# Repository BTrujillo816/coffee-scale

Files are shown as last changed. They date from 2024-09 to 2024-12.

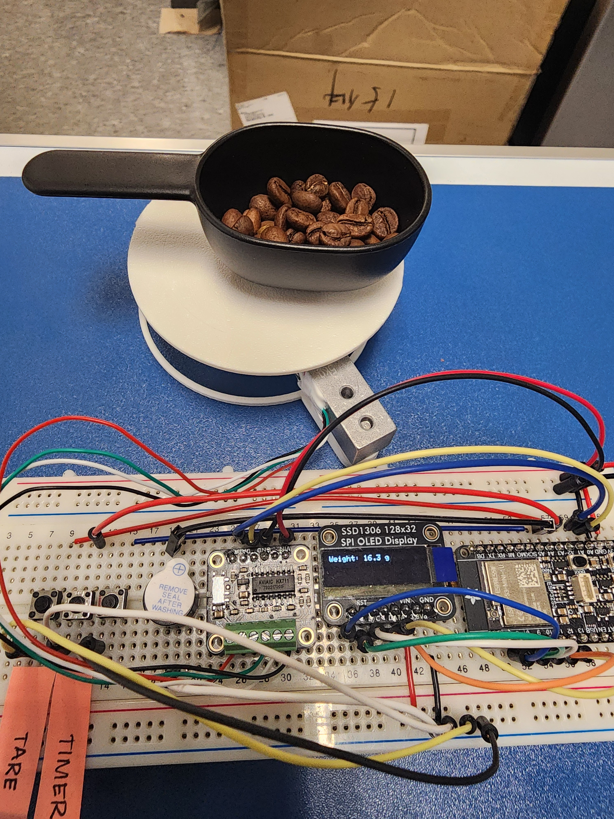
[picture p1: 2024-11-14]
documentation/TestDocument.assets/Small_weight_test_result.jpg

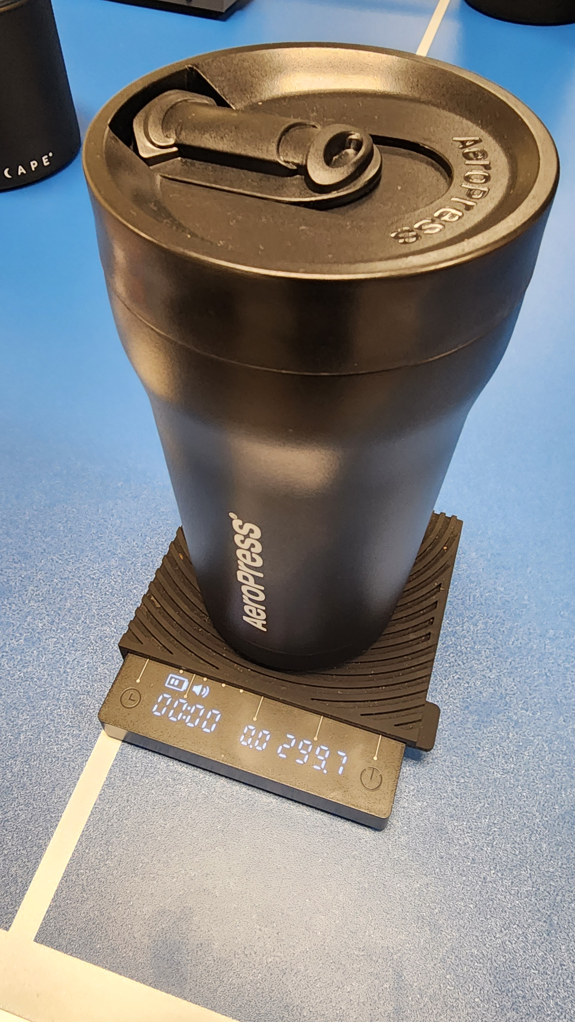
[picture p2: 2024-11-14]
documentation/TestDocument.assets/Medium_weight_test_control.jpg

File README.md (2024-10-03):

# ECET 430 Project: Digital Coffee Scale

This is a project for NJIT's ECET 430 - Electronics Manufacturing class.

## Purpose

This digital coffee scale will display weight measurements, flow rate, and include a built-in timer. It will also be able to send brew parameters through WiFi or Bluetooth to an App or other interface.

## Repo Layout

- `hardware` KiCad project with schematic, pcb layout, plots, drawings
- `software` ESP32 firmware and Arduino IDE setup
- `documentation` Technical documentation and user manual
- `logbook` Markdown files for progress updates

## Usage

See the [user documentation](documentation/UserDocumentation.md).

## Design

See the [design decision document](documentation/DesignDecisions.md).

## Credit

This project was made possible by borrowing from great designs, including:

- ABC's wearable widget, https://github.com/example/project
- XYZ's battery management, https://github.com/example/otherproject

## Author

Written by Brandon Trujillo and Miguel Takinan, 2024

## License

This work is available under the [Creative Commons Attribution-ShareAlike License 4.0](https://en.wikipedia.org/wiki/Wikipedia:Text_of_the_Creative_Commons_Attribution-ShareAlike_4.0_International_License). A local copy is available at [LICENSE.md](LICENSE.md).

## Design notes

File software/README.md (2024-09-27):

# Digital Coffee Scale Software

ESP32-S3 firmware project

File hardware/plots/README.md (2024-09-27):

# Digital Coffee Scale Hardware

PCB renderings, schematic PDFs, board images

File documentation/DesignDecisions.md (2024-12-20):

# Major Moving Parts
- Power
    - Battery
        - LIPO
            - MCP73831-based circuit for charging
- UI
    - Display
    - Buttons
- Enclosure
    - Laser Cut Acrylic
    - 3D Printed
- Microcontroller
    - ESP32
- Sensors
    - Load Cell
    - HX711
# Sections/Block Diagram
```mermaid 
flowchart TD
    A[ESP32] 
    B[Power]
    A -->C[User Interface] --> D[OLED Display] 
    A -->E[Enclosure] --> F[3D Printed Case]
    A -->G[Sensors] --> |HX711|I[Load Cell] 
    B -->K[LiPo]
    B -->L[MCP7831]
```
# Design Approaches
- Uses LiPo battery for rechargeability
- Uses ESP32 for its IoT capabilities i.e WiFi and Bluetooth
- Uses an E-ink display over LCD/LED to save on power consumption
- Uses an HX711 to interface with the load cell easily

# Major Component Selection
- MCP73831: https://www.digikey.com/en/products/detail/microchip-technology/MCP73831T-2ACI-OT/964301
- LiPo Battery: https://www.digikey.com/en/products/detail/sparkfun-electronics/PRT-13851/6605199
- eInk Display: https://www.digikey.com/en/products/detail/adafruit-industries-llc/1028/10650647
- ESP32: https://www.digikey.com/en/products/detail/adafruit-industries-llc/5885/22596418
- Load Cell: https://www.digikey.com/en/products/detail/adafruit-industries-llc/4540/12323569
- HX711 Breakout: https://www.digikey.com/en/products/detail/adafruit-industries-llc/5974/24639130

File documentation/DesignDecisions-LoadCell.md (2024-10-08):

# Load Cell + HX711 Design Decisions

## Calculations

### Load Cell

#### Voltage Output

$$V_{OUT}=V_{S}\times V_{E}$$

- $V_{OUT}$: Output from Load Cell
- $V_S$: Voltage Sensitivity
- $V_E$ = Excitation Voltage

### HX711

#### Full Scale Input Differential Voltage (FSR)

- Gain of 128: $\pm 20mV$
- Gain of 64: $\pm 40mV$
- Gain of 32: $\pm 80mV$

#### ADC Step Size

The data output from the ADC is a 24-bit 2's complement value.

ADC Step Size $= \frac{FSR\times2}{2^{24}}$

#### Saturation

[In Progress]

## Example Situation

Given a 1 kg Load Cell with $V_{S}=20 \space mV/V$ sensitivity and an excitation voltage of $V_E=5 \space V$

Max Output Voltage: 

$V_{OUT}=20\space mV/V\times5 \space V=100\space mV$

If an object weighs 500 g, then the output voltage (input into HX711) would be

$V_{OUT}=\frac{500}{1000}\times100=50\space mV$

If the input signal into the HX711 were to exceed these the Full Scale Input Differential Voltage, the output from the HX711 would be saturated.

$50 \space mV$ is beyond the range of $\pm 20mV$ and $\pm 40mV$; therefore, the only appropriate gain value to use is 32, which gives a range of $\pm 80mV$

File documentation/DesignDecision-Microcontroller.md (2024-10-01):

### Microcontroller Options

- ESP32-S3
- Arduino

### Pros and Cons

- ESP32-S3

  - Pros
    - IoT Capability (Bluetooth and Wi-Fi)
    - Arduino IDE compatible
    - Greater processing speed
    - Sleep modes
  - Cons
    - More expensive than ATMEGA328PB-MU
    - Smaller operational voltage range (2.2 to 3.6V)
- ATMEGA328PB-MU

  - Pros
    - Greater operational voltage range (1.8 to 5.5V)
    - Easier to work with (prior experience)
    - Lower power draw

  - Cons
    - No Wi-Fi without external module
    - No Bluetooth capability without external module

### Decision Factors

We decided to use an ESP32-S3 primarily because of its IoT capabilities (Wi-Fi and Bluetooth compatibility) and its compatibility with the Arduino IDE.

### Microcontroller Resources

Built-in Peripherals

- PWM
  - eInk Display
- RTC
  - External Wakeup

Connectivity	

- SPI
  - eInk Display
- BLE
  - App connectivity/data collection
- Wi-Fi
  - App connectivity/data collection

Memory Planning

- Calibration settings

GPIO

- Pushbuttons

- LEDs

- HX711

Power supply plan

- Sleep modes

### Parameters

eInk Display (UC8151d)

- Clock rate for SPI interface
- Display resolution
- Frame rate

HX711

- Sampling rate
- Gain selection

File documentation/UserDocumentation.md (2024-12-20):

# Digital Coffee Scale User Manual

## Product Purpose
- The Coffee Scale Project is designed to replicate a professional coffee scale, providing precise measurements for brewing coffee. The scale automatically weighs objects, shows brewing parameters, and interacts with the user through physical controls and oled display. The product is powered by a LiPo battery and built around the ESP32 microcontroller for versatile connectivity and functionality.

## Operation
### Initial Setup
1. Power
- Make sure battery is charged. Connect to USB-C if needs charging. 
- Press wake up button to turn product on.

2. Calibration
- Ensure the scale is on a flat surface.
- Press the Tare Button to reset the weight to zero.

### Button Functions

1. Tare Button
- Action: Press to reset the scale reading to zero.
- Feedback: The buzzer will emit a short beep, and the display will show "Scale Tared"
- Use Case: Use this when the scale is loaded with a container and you want to measure the contents only.

2. Timer Button
- Action:
    - Press once to start the timer.
    - Press again to stop the timer.
- Feedback: The buzzer will emit a short beep for each action.
- Display:
    - When running, the timer shows elapsed time in seconds (e.g., "Timer: 10 s").
    - When stopped, the timer display freezes.
- Use Case: Use this to track brewing time or other timed processes.

## Weight and Flow Rate Display

1. Weight
- Displayed as: "Weight: X.X g"
    - Updates continuously as items are added or removed.
    - Minimum detectable weight is 1 gram.

2. Flow Rate
    - Displayed as: "Flow Rate: X.X g/s"
    - Calculates the rate of weight change every second.
    - Updates if the flow rate exceeds 0.5 g/s.

## Sleep Mode

1. Activation
- The device enters deep sleep mode after 30 seconds of inactivity.
- Inactivity is defined as:
    - Weight below 1 gram.
    - Timer is not running.

2. Wake-Up
- Press the wake-up button to reactivate the device.

## Maintenance
1. Clean the scale surface regularly to ensure accurate readings
2. Avoid overloading the strain gauge to prevent damage
3. Recharge the battery periodically to maintain portability

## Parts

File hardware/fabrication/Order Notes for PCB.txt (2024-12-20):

Order Notes for PCB

Project Name: Coffee Scale PCB
Dimensions: 71.5 mm x 43.25 mm

Instructions:
If any errors or discrepancies are identified in the provided files, you have my authorization to make any necessary adjustments to ensure the board works as intended.

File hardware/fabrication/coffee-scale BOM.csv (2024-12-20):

Reference | Value | Footprint | Qty | MPN
C1,C2,C3,C4,C5,C6 | 10uF | Capacitor_SMD:C_1206_3216Metric_Pad1.33x1.80mm_HandSolder | 6
C7,C9 | 100nF | Capacitor_SMD:C_1206_3216Metric_Pad1.33x1.80mm_HandSolder | 2
C8 | 10uf | Capacitor_SMD:C_1206_3216Metric_Pad1.33x1.80mm_HandSolder | 1
C10,C11 | 20p | Capacitor_SMD:C_1206_3216Metric_Pad1.33x1.80mm_HandSolder | 2
D1 | ~ | Diode_SMD:D_SOD-128 | 1 | PMEG4050EP,115
D2 | LED | LED_SMD:LED_1206_3216Metric_Pad1.42x1.75mm_HandSolder | 1
D4 | D_Schottky_Filled | Diode_SMD:D_SOD-128 | 1 | DMG2301L-7
J1 | Conn_01x08 | Connector_PinHeader_2.54mm:PinHeader_1x08_P2.54mm_Vertical | 1
J2 | Conn_01x04 | Connector_PinHeader_2.54mm:PinHeader_1x04_P2.54mm_Vertical | 1
J3 | Conn_01x02 | Connector_JST:JST_PH_S2B-PH-K_1x02_P2.00mm_Horizontal | 1
J4 | USB C | Connector_USB:USB_C_Receptacle_GCT_USB4085 | 1 | USB4085-GF-A
LS1 | Speaker | Buzzer_Beeper:Buzzer_12x9.5RM7.6 | 1
Q1 | DMG3415U | Package_TO_SOT_SMD:SOT-23 | 1 | DMG2301L-7
Q2 | S8550 | Package_TO_SOT_SMD:SOT-23-3 | 1 | S8550
Q3 | BSS138 | Package_TO_SOT_SMD:SOT-23 | 1 | BSS138
R1,R2 | 100k | Resistor_SMD:R_1206_3216Metric_Pad1.30x1.75mm_HandSolder | 2
R3,R4,R9,R10 | 5.1k | Resistor_SMD:R_1206_3216Metric_Pad1.30x1.75mm_HandSolder | 4
R5,R6,R7,R8 | 100 | Resistor_SMD:R_1206_3216Metric_Pad1.30x1.75mm_HandSolder | 4
R11 | 10k | Resistor_SMD:R_1206_3216Metric_Pad1.30x1.75mm_HandSolder | 1
R12,R13 | 22 | Resistor_SMD:R_1206_3216Metric_Pad1.30x1.75mm_HandSolder | 2
SW1,SW2,SW3 | SW_Push | Button_Switch_SMD:SW_SPST_Omron_B3FS-105xP | 3
TP1,TP2,TP3,TP4,TP5,TP6 | TestPoint_Small | -- mixed values -- | 6
U1 | ESP32-S3 | RF_Module:ESP32-S3-WROOM-1 | 1 | ESP32-S3-WROOM-1-N16
U2 | HX711 | Package_SO:SOP-16_3.9x9.9mm_P1.27mm | 1 | HX711
U3 | MCP73832-5-OT | Package_TO_SOT_SMD:SOT-23-5 | 1 | MCP73832T-5ACI/OT
U4 | AP2112/RT9080-3.3 | Package_TO_SOT_SMD:SOT-89-5_Handsoldering | 1 | AP2112R5-3.3TRG1

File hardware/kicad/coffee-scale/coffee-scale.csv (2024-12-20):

Reference | Footprint | Qty | MPN
C1,C2,C3,C4,C5,C6 | Capacitor_SMD:C_1206_3216Metric_Pad1.33x1.80mm_HandSolder | 6
C7,C9 | Capacitor_SMD:C_1206_3216Metric_Pad1.33x1.80mm_HandSolder | 2
C8 | Capacitor_SMD:C_1206_3216Metric_Pad1.33x1.80mm_HandSolder | 1
C10,C11 | Capacitor_SMD:C_1206_3216Metric_Pad1.33x1.80mm_HandSolder | 2
D1 | Diode_SMD:D_SOD-128 | 1 | PMEG4050EP,115
D2 | LED_SMD:LED_1206_3216Metric_Pad1.42x1.75mm_HandSolder | 1
D4 | Diode_SMD:D_SOD-128 | 1 | DMG2301L-7
J1 | Connector_PinHeader_2.54mm:PinHeader_1x08_P2.54mm_Vertical | 1
J2 | Connector_PinHeader_2.54mm:PinHeader_1x04_P2.54mm_Vertical | 1
J3 | Connector_JST:JST_PH_S2B-PH-K_1x02_P2.00mm_Horizontal | 1
J4 | Connector_USB:USB_C_Receptacle_GCT_USB4085 | 1 | USB4085-GF-A
LS1 | Buzzer_Beeper:Buzzer_12x9.5RM7.6 | 1
Q1 | Package_TO_SOT_SMD:SOT-23 | 1 | DMG2301L-7
Q2 | Package_TO_SOT_SMD:SOT-23-3 | 1 | S8550
Q3 | Package_TO_SOT_SMD:SOT-23 | 1 | BSS138
R1,R2 | Resistor_SMD:R_1206_3216Metric_Pad1.30x1.75mm_HandSolder | 2
R3,R4,R9,R10 | Resistor_SMD:R_1206_3216Metric_Pad1.30x1.75mm_HandSolder | 4
R5,R6,R7,R8 | Resistor_SMD:R_1206_3216Metric_Pad1.30x1.75mm_HandSolder | 4
R11 | Resistor_SMD:R_1206_3216Metric_Pad1.30x1.75mm_HandSolder | 1
R12,R13 | Resistor_SMD:R_1206_3216Metric_Pad1.30x1.75mm_HandSolder | 2
SW1,SW2,SW3 | -- mixed values -- | 3
TP1,TP2,TP3,TP4,TP5,TP6 | -- mixed values -- | 6
U1 | RF_Module:ESP32-S3-WROOM-1 | 1 | ESP32-S3-WROOM-1-N16
U2 | Package_SO:SOP-16_3.9x9.9mm_P1.27mm | 1 | HX711
U3 | Package_TO_SOT_SMD:SOT-23-5 | 1 | MCP73832T-5ACI/OT
U4 | Package_TO_SOT_SMD:SOT-89-5_Handsoldering | 1 | AP2112R5-3.3TRG1

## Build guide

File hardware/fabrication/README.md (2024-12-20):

# Digital Coffee Scale Fabrication Files

Gerbers, BOM, ordering instructions

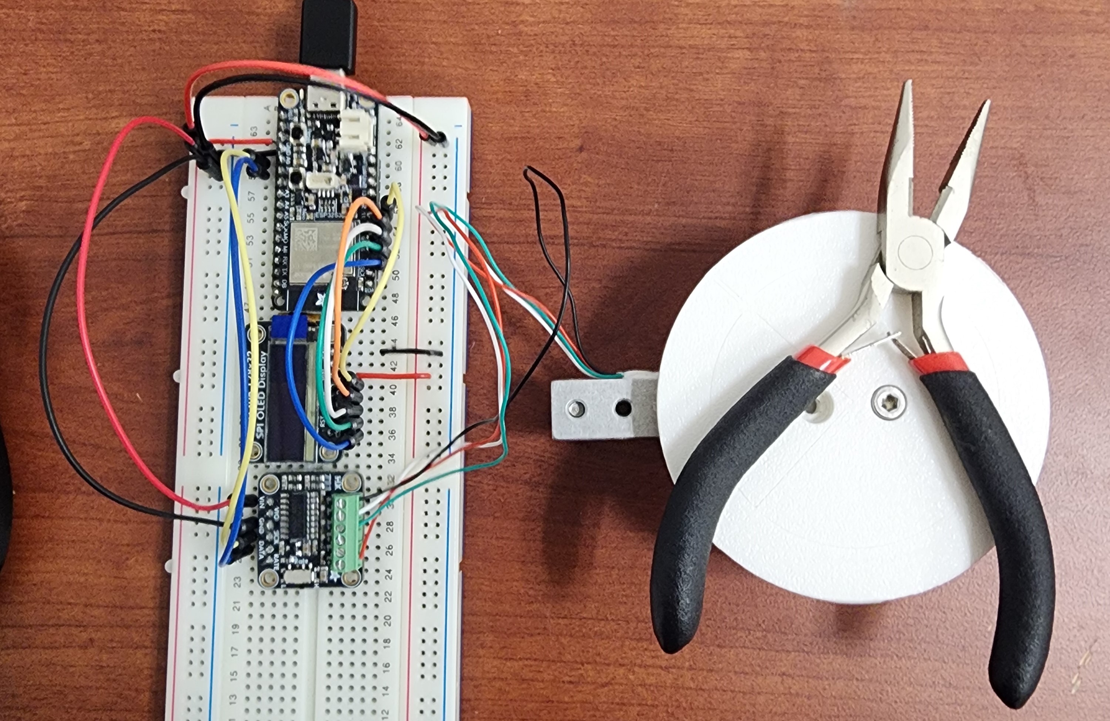
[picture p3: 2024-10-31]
logbook/10-30-24.assets/Wiring.jpg

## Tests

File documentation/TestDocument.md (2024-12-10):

# Test Document

## Precision Testing

### Test 1 - Does it show the same value for a given object?

#### Equipment Used

- Coffee Grinder
- Timemore [Black Mirror Nano Scale](https://www.timemore.com/products/timemore-black-mirror-nano-espresso-coffee-weighing-timing-black)
- [Breadboard prototype](https://github.com/BTrujillo816/coffee-scale/blob/main/documentation/TestDocument.assets/Current_prototype_11-13-24.jpg)

#### Criteria

- Given: An object of known weight
- When: The object is removed and placed again
- Then: The scale should display the same value each time
- Acceptable Range: $\pm10$%

#### Results

| Placement | Control (g) | Test (g) | Percent Error (%) |
| --- | --- | --- | --- |
| 1 | 380.4 | 380.3 | 0.02 |
| 2 | 380.4 | 380.4 | 0 |
| 3 | 380.4 | 380.5 | 0.05 |

The object was picked up and placed three times after the initial placement, as seen in the [video](https://github.com/BTrujillo816/coffee-scale/blob/main/documentation/TestDocument.assets/Test_Precision.mp4). The results of this test fall within the acceptable range, therefore the system is precise. However, the weight output tends to fluctuate, likely due to noise.

### Test 2 - Does it show the same value over a long period of time?

#### Equipment Used

- Coffee Grinder
- Timemore [Black Mirror Nano Scale](https://www.timemore.com/products/timemore-black-mirror-nano-espresso-coffee-weighing-timing-black)
- [Breadboard prototype](https://github.com/BTrujillo816/coffee-scale/blob/main/documentation/TestDocument.assets/Current_prototype_11-13-24.jpg)

#### Criteria

- Given: An object of known weight
- When: The object remains on the scale for an extended period of time
- Then: The scale should continuously show the same weight for the same period of time
- Acceptable Range: $\pm 5$%

#### Results

| Time (s) | Control (g) | Test (g) | Percent Error (%) |
| --- | --- | --- | --- |
| 5 | 298.7 | 298.4 | 0.10 |
| 15 | 298.7 | 298.5 | 0.07 |
| 30 | 298.7 | 298.9 | 0.07 |

When an object remains on the scale, the weight display tends to fluctuate; however, because the fluctuations are within an acceptable range below 5%, the system is still precise. The weight fluctuation could be potentially be solved through noise reduction measures and a redesign the load cell chassis.

## Accuracy Testing

### Test 1 - Benchmark weight against existing products

#### Equipment Used

- Coffee scoop (light weight)
- Metal bottle (medium weight)
- Coffee Grinder (heavy weight)
- Timemore [Black Mirror Nano Scale](https://www.timemore.com/products/timemore-black-mirror-nano-espresso-coffee-weighing-timing-black)
- [Breadboard prototype](https://github.com/BTrujillo816/coffee-scale/blob/main/documentation/TestDocument.assets/Current_prototype_11-13-24.jpg)

#### Criteria

- Acceptable Range: $\pm 10%$%

#### Results

| Object | Control (g) | Test (g) | Percent Error (%) |
| --- | --- | --- | --- |
| Coffee Scoop | [16.3](https://github.com/BTrujillo816/coffee-scale/blob/main/documentation/TestDocument.assets/Small_weight_test_control.jpg) | [16.3](https://github.com/BTrujillo816/coffee-scale/blob/main/documentation/TestDocument.assets/Small_weight_test_result.jpg) | 0 |
| Metal Bottle | [299.7](https://github.com/BTrujillo816/coffee-scale/blob/main/documentation/TestDocument.assets/Medium_weight_test_control.jpg) | [299.3](https://github.com/BTrujillo816/coffee-scale/blob/main/documentation/TestDocument.assets/Medium_weight_test_result.jpg) | 0.13 |
| Coffee Grinder | [380.8](https://github.com/BTrujillo816/coffee-scale/blob/main/documentation/TestDocument.assets/Large_weight_test_control.jpg) | [380.2](https://github.com/BTrujillo816/coffee-scale/blob/main/documentation/TestDocument.assets/Large_weight_test_result.jpg) | 0.15 |

All tests were within an acceptable range, therefore, our system is accurate.

### Test 2 - Benchmark time against computer/phone clock

#### Equipment Used

- Timemore [Black Mirror Nano Scale](https://www.timemore.com/products/timemore-black-mirror-nano-espresso-coffee-weighing-timing-black)
- Breadboard prototype

#### Criteria

- Acceptable Range: $\pm 5$%

#### Results

As shown in the [video](https://github.com/BTrujillo816/coffee-scale/blob/main/documentation/TestDocument.assets/Test_Timer.mp4), both timers seem to increment at the same rate. Therefore, we can say that our system is accurate in its timing.

### Test 3 - Benchmark flow-rate calculation against existing products

#### Equipment Used

- Timemore [Black Mirror Nano Scale](https://www.timemore.com/products/timemore-black-mirror-nano-espresso-coffee-weighing-timing-black)
- [Breadboard](https://github.com/BTrujillo816/coffee-scale/blob/main/documentation/TestDocument.assets/Current_prototype_11-13-24.jpg) prototype
- Metal cup
- Paper cup

#### Criteria

- Given: Water flows from a container at a known flow rate
- When: Water flows onto the scale
- Then: The scale should display an accurate flow rate measurement

#### Result

We have determined from our [test](https://github.com/BTrujillo816/coffee-scale/blob/main/documentation/TestDocument.assets/Functionality_Flow_Rate.mp4) that a more consistent, controllable method should be used to measure flow rate. In the future, we'll use an object that provides a consistent flow rate (such as a funnel) and benchmark the scale against the Timemore scale.

## Manual Testing

#### Equipment Used

- Timemore [Black Mirror Nano Scale](https://www.timemore.com/products/timemore-black-mirror-nano-espresso-coffee-weighing-timing-black) (or any timer)
- [Breadboard](https://github.com/BTrujillo816/coffee-scale/blob/main/documentation/TestDocument.assets/Current_prototype_11-13-24.jpg) prototype
- Any weight

#### Test 1 - Check sleep timer functionality after inactivity

#### Procedure

- Wake up the scale by pressing the wakeup button
- Place weight on scale and wait 30 seconds
- Observe if the scale remains on after 30 seconds
- Remove weight and leave the scale idle for 30 seconds
- Observe if the scale automatically powers off after 30 seconds

- Pass Criteria: The scale turns on when power button is pressed and turns off after 30 seconds of no activity

#### Result

In the [video](https://github.com/BTrujillo816/coffee-scale/blob/main/documentation/TestDocument.assets/Test_Timer.mp4), an object is placed on the scale to prevent the system from going to sleep. At 32 seconds, the object is removed and the system shuts off 30 seconds later at 1:02. This accurate shows the sleep timer is functioning properly.

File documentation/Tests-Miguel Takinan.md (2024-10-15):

# Test Criterias by Miguel Takinan

## Guides
1. [Automatic vs Manual Testing](https://www.geeksforgeeks.org/software-engineering-differences-between-manual-and-automation-testing/)
2. [Given-When-Then](https://martinfowler.com/bliki/GivenWhenThen.html)

## Test
1. Power and Auto-off Functionality
    - Test Type: Manual
    - Objective: Check the power functions and auto-off function after inactivity
    - Test Steps:
        - Turn the scale on by pressing the power button
        - Leave the scale idle for 30 seconds
        - Observe if the scale automatically powers off after 30 seconds
    - Pass Criteria: The scale turns on when power button is pressed and turns off after 30 seconds of no activity

2. Accuracy of Weight Measurement
    - Test Type: Manual, Given-When-Then
    - Objective: Ensure the scale measures weight accurately
    - Test Steps:
        - Given an accurate weight of 100g
        - When the weight is placed on the scale
        - Then the scale should display the correct weight of 100g
    - Pass Criteria: The displayed weight is correct within a small margin of error

3. Display Accuracy and Speed
    - Test Type: Manual, Given-When-Then
    - Objective: Ensure the display shows weight measurements accurately and updates in real-time without noticeable delay
    - Test Steps:
        - Given the scale is powered on
        - When a series of weights starting from 0g, 50g and 100g are placed on the scale one at a time
        - Then the display should show the correct weight for each measurement immediately
    - Pass Criteria: The display shows the correct weight for each tested weight within one second

4. Flow Rate Detection
    - Test Type: Manual
    - Objective: Ensure the scale accurately detects and displays flow rate
    - Test Steps:
        - Start pouring water slowly onto a container placed on the scale
        - Observe if the scale continuously displays the flow rate in grams per second
        - Compare flow rate readings against a stopwatch and a graduated cylinder for accuracy
    - Pass Criteria: The scale’s flow rate closely matches the manual measurements

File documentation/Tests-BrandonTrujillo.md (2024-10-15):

# Tests - Brandon Trujillo

## Performance Testing

Types-of-Performance-testing-1024

### Load Testing

What happens when a weight that exceeds the Load Cell's rating is placed on the scale?

- Test different types of loads
  - Anticipated loads
  - Excessive loads

### Endurance Testing

**Precision**

- Does it show the same value for a given object?
  - Given: An object of known weight
  - When: The object is removed and placed again
  - Then: The scale should display the same value each time
- Does it show the same value over a long period of time?
  - Given: An object of known weight
  - When: The object remains on the scale for an extended period of time
  - Then: The scale should continuously show the same weight for the same period of time

### Benchmark Testing

**Accuracy**

- Benchmark weight against existing products
- Benchmark time against computer/phone clock
- Benchmark flow-rate calculation against existing products

### Speed Testing

- Measure execution time of each section of code
  - Print time of execution to serial monitor

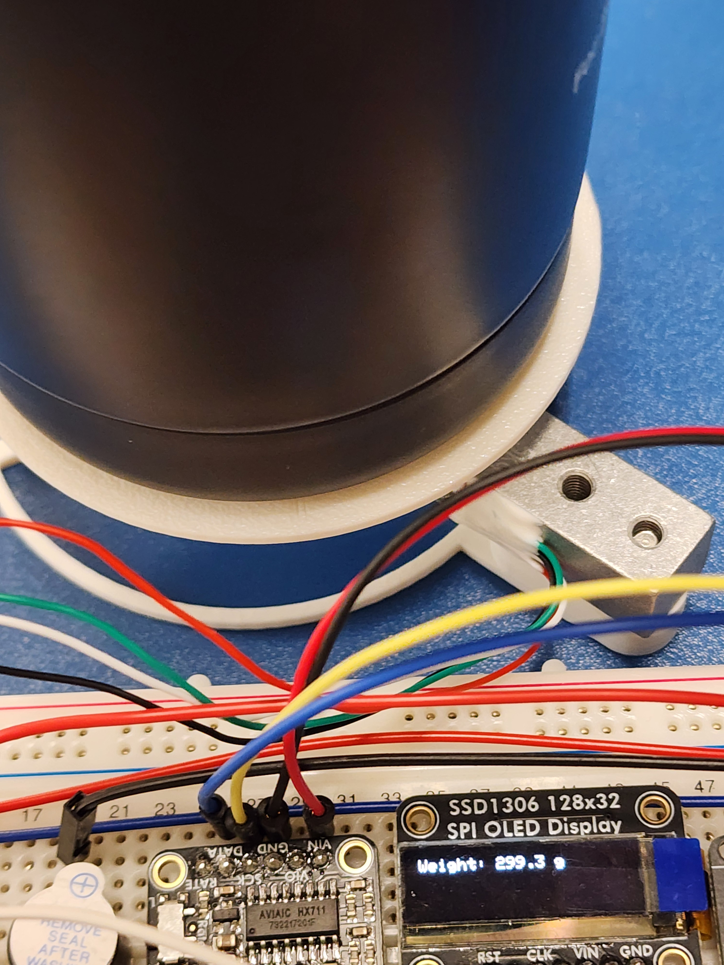
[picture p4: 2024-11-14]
logbook/11-13-24.assets/Medium_weight_test_result.jpg

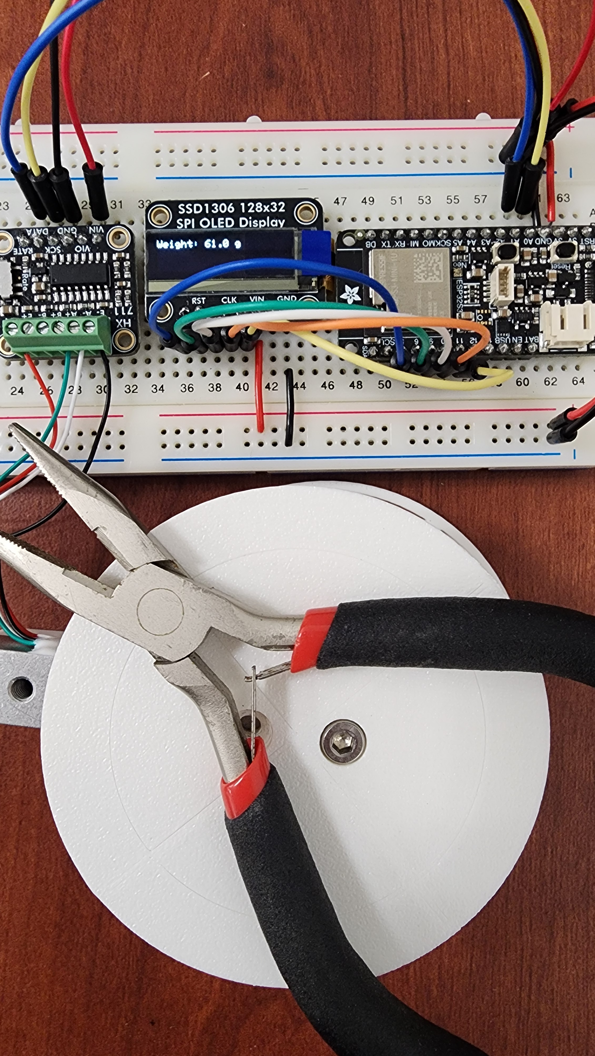
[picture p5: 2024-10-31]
logbook/10-30-24.assets/Result_Oled_LoadCell_Test.jpg

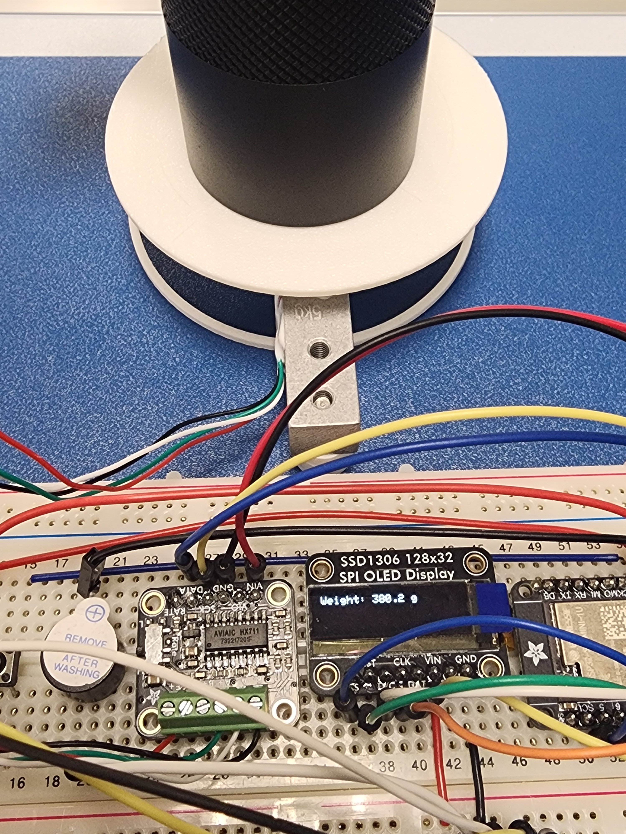
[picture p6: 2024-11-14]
logbook/11-13-24.assets/Large_weight_test_result.jpg

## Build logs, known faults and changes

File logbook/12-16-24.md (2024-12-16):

# 12/16/2024
## PCB Edits
    - Changed ESP32 footprint
    - Changed USB footprint
    - Finished routing all traces
    - DRC found no errors except some warnings

## DRC Errors
    - Copper zone being cut off because of running traces on the bottom layer
        - Causing ground connection issues(annoying issue to tackle)
            - Made bottom layer traces as close to each other and only as needed
            - Made sure theres no island copper fill
    - Ignored USB and PCB clearance errors
    - Minor errors all around like having a silkscreen minumum height of .8 mm were fixed

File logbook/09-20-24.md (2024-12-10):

# 09-20-24

## [Blink an LED with an ESP32](https://github.com/BTrujillo816/coffee-scale/issues/6)

### Components

- ESP32-S3
- $220 \ohm$ resistor
- LED

### Notes

- [Wokwi Project](https://wokwi.com/projects/409566066184866817)

- I used this [tutorial](https://makeabilitylab.github.io/physcomp/esp32/led-blink.html) to blink a singular LED on Wokwi

## [Use ESP32 to interface with HX711 and Load Cell in Wokwi](https://github.com/BTrujillo816/coffee-scale/issues/7)

### Components

- ESP32-S3
- HX711
- Load Cell

### Notes

[Wokwi Project](https://wokwi.com/projects/409582446772088833)

- I used the Example Arduino Sketch from the [Hobby Components forum post](https://forum.hobbycomponents.com/viewtopic.php?f=73&t=1763) by Andrew Davies
  - I prefer this to using the HX711 Arduino library as I eventually want to learn how to implement this in ESP-IDF using C.
    - The HX711 datasheet contains a reference driver in both ASM and C

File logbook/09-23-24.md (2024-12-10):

# 09-23-24

## [Interface with eInk Display using ESP32 on Wokwi](https://github.com/BTrujillo816/coffee-scale/issues/9)

### Details

- Status: Incomplete
- Hardware
  - ESP32-S3
  - ePaper 2.9"
- Software
  - Wokwi
  - C++

### Notes

- I cannot find an example Wokwi project using the [Adafruit EDP Library](https://github.com/adafruit/Adafruit_EPD) that works properly

  - The error seems to be with the GXEPD2 library

    - ```
      Error installing GxEPD2: Library install failed: testing local archive integrity: testing archive size: fetched archive size differs from size specified in index: 176128 != 4501132
      ```

- I'll need to learn how to upload custom libraries
  - It might be easier if I set up Wokwi for VS Code

## [Start Project Schematic](https://github.com/BTrujillo816/coffee-scale/issues/10)

### Details 

- Status: Incomplete
- Software
  - KiCAD

### Notes

- We needed to make a custom symbol within KiCAD
  - This can be found within
- I cannot figure out what electrical type MISO and MOSI should be
  - [Related Forum Post](https://forum.kicad.info/t/electrical-type-for-spi-device-miso-pins/9444)
- I think Adafruit really wants us to use a breakout board to interface with the eInk display
  - Without it, we'd have to solder headers onto the display if we wanted to use it on a breadboard

### Misc

```
// 2.9" Tricolor Featherwing or Breakout with UC8151D chipset
// ThinkInk_290_Tricolor_Z13 display(EPD_DC, EPD_RESET, EPD_CS, SRAM_CS,
// EPD_BUSY, EPD_SPI);
```

- I found this on the [Adafruit EDP Library](https://github.com/adafruit/Adafruit_EPD). This might give insight on to what data pins actually matter.

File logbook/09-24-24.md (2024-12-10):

# 09-24-24

## [Start Project Schematic](https://github.com/BTrujillo816/coffee-scale/issues/10)

### Details

- Status: Version 001
- Hardware
  - ESP32-S3
  - HX711
  - Custom UC8151D
  - Custom Strain Gauge
  - MCP72831

### Wiring Guide

#### Load Cell Wiring Guide to HX711
    - E+ (red wire) stands for Excitation Positive of the load cell
        - Connects to the Analog Voltage Supply Pin (AVDD/VIN) of the HX711
    - E- (black ire) stands for Excitation Negative of the load cell
        - Connects to the Analog Ground (AGND/GND) of the HX711
    - A+ (white wire) stands for Signal Positive of the load cell
        - Connects to the Positive Input for channel A (INA+ or A+) of the XH711
    - A- (green wire) stands for Signal Negative of the load cell
        - Connect to the Negative Input for channel A (INA- or A-) of the HX711
    
    *** Important: Since no datasheet came with the acquired load cell. Assume manufacturer followed this convention.
        1. Red Wire (E+): Positive excitation
        2. Black Wire (E-): Negative excitation
        3. White Wire (A+): Positive signal output
        4. Green Wire (A-): Negative signal output

#### HX711 to ESP32-S3
    - HX711 SCK (Serial Clock) or PD_SCK 
        - Connect to any GPIO
    - HX711 DATA (Data Output) or DOUT
        - Connect to any GPIO
    - HX711 E+ (Excitation Positive)
        - Connect to AVDD/VIN
    - HX711 E- (Excitation Negative)
        - Connect to GND

#### ESP32 to E-ink Display
    - Power Connections:
        - VIN → Connect to 5V (or 3.3V, depending on your display’s requirement)
        - 3.3V → Connect to VDD3P3 on the ESP32-S3
        - GND → Connect to GND on the ESP32-S3
    
    - SPI Connections:
        - SCK → Connect to SCK of ESP32-S3 (GPIO36 on the ESP32-S3 Feather)
        - MISO → Connect to MISO of ESP32-S3 (GPIO37 on the ESP32-S3 Feather)
        - MOSI → Connect to MOSI of ESP32-S3 (GPIO35 on the ESP32-S3 Feather)
        - ECS (Chip Select) → Connect to any GPIO 
        - D/C (Data/Command) → Connect to any GPIO
        - SRCS (Source Select) → Connect to any GPIO 
        - SDCS (Data Chip Select) → Connect to any GPIO 
        - RST (Reset) → Connect to any GPIO
        - BUSY → Connect to any GPIO
        - ENA (Enable) → Connect to any GPIO
    
    *** Necessary Pins for E-ink Display
        - SCK: Required for clocking the data into the E-ink display.
        - MISO: Typically used for data feedback from the E-ink display to the ESP32-S3. Not always necessary unless display requires it for certain operations (like reading status).
        - MOSI: Essential for sending data from the ESP32-S3 to the E-ink display.
        - ECS: This is important to tell the E-ink display when to listen to the data being sent. Without this, the display may not respond correctly.
        - D/C : Important for distinguishing between data and command instructions sent to the display. It helps the display interpret what type of data it is receiving.
        - RST: Often required to initialize the display. Without this, may not be able to reset the display or clear it properly.
    
    *** Optional Pinks for E-ink Display 
        - BUSY: Indicates when the display is busy processing data. It's useful for synchronizing operations but may not be strictly necessary for all applications.
        - SRCS: Might be used to select between different sources for data or power. Depending on your display.
        - SDCS: Similar to ECS, this pin is likely used to select the data source. If display has both ECS and SDCS, check the documentation to see if both are necessary, as sometimes they can serve similar purposes.
        - ENA: Typically enables or disables the display. It may be required to power on the display or enable certain functions. It's a common pin in various display modules.

### Notes

- ESP32-S3 has a lot more features than your standard ESP32. I am wondering if we should build this with an ESP32 instead of mounting on a ESP32-S3.

## [Interface with eInk display using ESP32-S3 IRL](https://github.com/BTrujillo816/coffee-scale/issues/11)

### Details

- Status: Incomplete
- Hardware:
  - Adafruit ESP32-S3 Feather
  - R: 220 $\ohm$ 
  - LED (Red)

### Soldering Headers

- In order to breadboard with these components, we had to solder headers onto the ESP32-S3, EYESPI Breakout Board, and HX711 breakout board
  - HX711
    - Might need to reflow some solder joints

### Notes

``````
A fatal error occurred: Could not open COM6, the port doesn't exist
Failed uploading: uploading error: exit status 2
``````

In order to solve this error, I have attempted the following:

- Uninstalled and reinstalled Arduino IDE
- Downloaded and installed CP210x USB to UART Bridge VCP Drivers from [here](https://www.silabs.com/developers/usb-to-uart-bridge-vcp-drivers?tab=downloads)
- Restarted my computer multiple times
- Swapped USB-C cable

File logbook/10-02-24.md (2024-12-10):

# 10-02-24

## [Blink LED IRL](https://github.com/BTrujillo816/coffee-scale/issues/13)

### Details

- Hardware
  - Adafruit Feather ESP32-S3 8MB No PSRAM
  - LED (Red)
  - 220 $\ohm$ Resistor
- Software
  - Arduino IDE
  - C++

### Notes

After many long hours of troubleshooting, I was finally able to blink an LED following a factory reset using this [tutorial](https://learn.adafruit.com/adafruit-esp32-s3-feather/factory-reset). Huzzah!



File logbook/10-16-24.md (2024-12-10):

# 10-16-24

## [Setup Wokwi for VS Code](https://github.com/BTrujillo816/coffee-scale/issues/12)

I was able to setup Wokwi for VS Code using [Wokwi's Guide](https://docs.wokwi.com/vscode/getting-started/). I'm interested in exploring PlatformIO as an IDE for programming the physical ESP32-S3 itself.

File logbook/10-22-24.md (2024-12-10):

# 10-22-24
## [Interface with HX711 and Load Cell IRL](https://github.com/BTrujillo816/coffee-scale/issues/14)

### Adafruit Example Code

```c++
#include <Arduino.h>
#include "HX711.h"

// HX711 circuit wiring
const int LOADCELL_DOUT_PIN = 9;
const int LOADCELL_SCK_PIN = 8;

HX711 scale;

void setup() {
  Serial.begin(57600);
  Serial.println("HX711 Demo");
  Serial.println("Initializing the scale");

  scale.begin(LOADCELL_DOUT_PIN, LOADCELL_SCK_PIN);

  Serial.println("Before setting up the scale:");
  Serial.print("read: \t\t");
  Serial.println(scale.read());      // print a raw reading from the ADC

  Serial.print("read average: \t\t");
  Serial.println(scale.read_average(20));   // print the average of 20 readings from the ADC

  Serial.print("get value: \t\t");
  Serial.println(scale.get_value(5));   // print the average of 5 readings from the ADC minus the tare weight (not set yet)

  Serial.print("get units: \t\t");
  Serial.println(scale.get_units(5), 1);  // print the average of 5 readings from the ADC minus tare weight (not set) divided
            // by the SCALE parameter (not set yet)
            
  scale.set_scale(765);
  //scale.set_scale(-471.497);                      // this value is obtained by calibrating the scale with known weights; see the README for details
  scale.tare();               // reset the scale to 0

  Serial.println("After setting up the scale:");

  Serial.print("read: \t\t");
  Serial.println(scale.read());                 // print a raw reading from the ADC

  Serial.print("read average: \t\t");
  Serial.println(scale.read_average(20));       // print the average of 20 readings from the ADC

  Serial.print("get value: \t\t");
  Serial.println(scale.get_value(5));   // print the average of 5 readings from the ADC minus the tare weight, set with tare()

  Serial.print("get units: \t\t");
  Serial.println(scale.get_units(5), 1);        // print the average of 5 readings from the ADC minus tare weight, divided
            // by the SCALE parameter set with set_scale

  Serial.println("Readings:");
}

void loop() {
  Serial.print("one reading:\t");
  Serial.print(scale.get_units(), 1);
  Serial.print("\t| average:\t");
  Serial.println(scale.get_units(10), 5);

  delay(5000);
}
```

### Random Nerd Tutorials Code

```c++
/*
  Rui Santos
  Complete project details at https://RandomNerdTutorials.com/arduino-load-cell-hx711/

  Permission is hereby granted, free of charge, to any person obtaining a copy
  of this software and associated documentation files.

  The above copyright notice and this permission notice shall be included in all
  copies or substantial portions of the Software.
*/

// Calibrating the load cell
#include "HX711.h"

// HX711 circuit wiring
const int LOADCELL_DOUT_PIN = 2;
const int LOADCELL_SCK_PIN = 3;

HX711 scale;

void setup() {
  Serial.begin(57600);
  scale.begin(LOADCELL_DOUT_PIN, LOADCELL_SCK_PIN);
}

void loop() {

  if (scale.is_ready()) {
    scale.set_scale();    
    Serial.println("Tare... remove any weights from the scale.");
    delay(5000);
    scale.tare();
    Serial.println("Tare done...");
    Serial.print("Place a known weight on the scale...");
    delay(5000);
    long reading = scale.get_units(10);
    Serial.print("Result: ");
    Serial.println(reading);
  } 
  else {
    Serial.println("HX711 not found.");
  }
  delay(1000);
}

//calibration factor will be the (reading)/(known weight)
```

### Notes

- The test code from adafruit library was not working as intended
    - The output is either 0 or some constant value that does not change no matter how much pressure is applied to the gauge

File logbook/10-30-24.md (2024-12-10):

# 10-30-24

## [Update schematic to include OLED display](https://github.com/BTrujillo816/coffee-scale/issues/18)

### General

- Added OLED (SSD1306) [datasheet](../coffee-scale\documentation\assets\SSD1306.pdf) to documentation branch

### Eagle File to KiCAD

- Why does Adafruit only offer Eagle files :c

### Symbol Creation

- Figured out that we don't need it anyways
  - Added 08x02 connectors to socket display

## [Make a Nice Readable Schematic](https://github.com/BTrujillo816/coffee-scale/issues/16)

### LiPo Battery Charger

- Replaced SparkFun ESP32 Thing circuit with prettier circuit from Adafruit ESP32-S3 Feather 

### Power and Filtering

- Changed custom JST connector to boring KiCAD 01x02 connector
  - I should place this on the left side to have it function clearly as an input

### Load Cell

- Edited symbol so no wires crisscross

### ADC

- Added No Connect flags

### Microcontroller

- Added No Connect flags

### Display

- Made wiring nice and pretty
- Added text
  - I should add more text about the actual display

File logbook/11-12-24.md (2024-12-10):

# 11-12-24

## [Add USB-C receptacle to schematic](https://github.com/BTrujillo816/coffee-scale/issues/24)

### General

- Added USB-C receptable

- Read this [article](https://dubiouscreations.com/2021/04/06/designing-with-usb-c-lessons-learned/) to learn more about reasoning behind design

  image-6-450x312

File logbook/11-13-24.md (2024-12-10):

# 11-13-24

## [Add pushbuttons to prototype](https://github.com/BTrujillo816/coffee-scale/issues/25)

- Added three button to do three different functionalities
    - Tare feature to zero the scale after putting weight when button is pressed
    - Timer function that starts to count and show on the OLED display when the button is pressed
    - Wake up
- Added an active buzzer for sound effects    

## [Configure Deep Sleep mode](https://github.com/BTrujillo816/coffee-scale/issues/23)

- Added a deep sleep mode by following this [website](https://randomnerdtutorials.com/esp32-deep-sleep-arduino-ide-wake-up-sources/)
- Currently, the threshold weight for deep sleep is <1g 

## [Create flow rate display algorithm](https://github.com/BTrujillo816/coffee-scale/issues/20)

- Although this works, we still need to figure out a better method of testing

## [Run tests on breadboard prototype](https://github.com/BTrujillo816/coffee-scale/issues/26)

- Tested the core functionalities of our prototype for our midterm presentation
    - More details can be found in our [testing document](https://github.com/BTrujillo816/coffee-scale/blob/main/documentation/TestDocument.md)
- Scale
    - Accuracy Test
        - Benchmarked three different objects to determine the scale's accuracy
    - Precision Test
        - Weighed the same object multiple times to determine consistency
- Timer
    - Ran a known timer at the same time to determine accuracy
- Deep sleep timer
    - Tested deep sleep timer by letting an object rest for more than 30 seconds, removing it, and then waiting

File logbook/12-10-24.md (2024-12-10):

# 12/10/24
## PCB Design
### Footprint
- Mostly chose the 1206 because apparently is SMD soldering friendly
- Some footprints like the USB and JSTPH im unsure of

### Routing
- Initially tried to do bottom copper as ground plane but having a hard time connecting signal traces in a two layer pcb
- resorted to going back to orthogonal method.
- Ended up mixing both.
    - Not the best routing/tracing job. 
    - Removed all the error in DRC.
        - Hopefully it works

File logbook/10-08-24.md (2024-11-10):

# 10-08-24

## [Create a Nice Readable Schematic](https://github.com/BTrujillo816/coffee-scale/issues/16)

### Rules/Conventions

- Signals should flow from left to right

- PWR on top, GND always down
  - 
- Lines should never be on an angle
  - Up, down, left, right
- Never, **ever** have lines going through your chip symbols
- Annotations should be horizontal
  - The person shouldn't have to tilt their head to read them

- Designators and their values can either be together on one side, or on opposite sides of a symbol

  - Just make sure you are consistent

- Set pins to snap grid when creating symbols

- No need to show footprints on schematic

- Net name should be on top of netlist/lines

- Don't assign nets to things that have ports (+3V3 net when you have a 3V3 port)

- Avoid crossing wires if possible

  - Edit symbol to move pins even if it doesn't match the physical layout

- Don't label nets if you are not going to use them

- Signify if a symbol is going out to prevent confusion (someone might think it's a completed circuit)

  



- Don't run wires through the schematic if you don't have to

- Connectors don't have to be next to the components; however, you must properly label the nets

- Net names should be meaningful and nonredundant

- Either change the symbol to all match the physical in mapping or group them up by functionality so that they support signal flow
  - If you edit for symbol flow, make sure that the inputs are on the left and outputs are on the right
- Be consistent with schematic symbols i.e. for capacitors, resistors
- Do not use decimal points for values in your schematic
  - 0.01uF > 100nF or 100n
- Use ports for outputs
- Label sections with notes
- Make LEDS and other symbols vertical
- Don't create four way junctions off a single node
- Designators can be renamed if you truly need to but keep it short and sweet
- Use A4 schematic size since we're yankees

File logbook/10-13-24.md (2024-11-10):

# 10-13-24

## [Interface with eInk display using ESP32-S3 IRL](https://github.com/BTrujillo816/coffee-scale/issues/11)

### Example Code for E-Ink from Adafruit
```
#include "Adafruit_ThinkInk.h"

#define EPD_DC 10
#define EPD_CS 5
#define EPD_BUSY -1 // can set to -1 to not use a pin (will wait a fixed delay)
#define SRAM_CS 11
#define EPD_RESET 9  // can set to -1 and sh\are with microcontroller Reset!
#define EPD_SPI &SPI // primary SPI

ThinkInk_290_Tricolor_Z13 display(EPD_DC, EPD_RESET, EPD_CS, SRAM_CS, EPD_BUSY, EPD_SPI);

void setup() {
  Serial.begin(115200);
  while (!Serial) {
    delay(10);
  }
  Serial.println("Adafruit EPD full update test in red/black/white");
  display.begin(THINKINK_TRICOLOR);
}

void loop() {
  Serial.println("Banner demo");
  display.clearBuffer();
  display.setTextSize(3);
  display.setCursor((display.width() - 144) / 2, (display.height() - 24) / 2);
  display.setTextColor(EPD_BLACK);
  display.print("Tri");
  display.setTextColor(EPD_RED);
  display.print("Color");
  display.display();

  delay(15000);

  Serial.println("Color rectangle demo");
  display.clearBuffer();
  display.fillRect(display.width() / 3, 0, display.width() / 3,
                   display.height(), EPD_BLACK);
  display.fillRect((display.width() * 2) / 3, 0, display.width() / 3,
                   display.height(), EPD_RED);
  display.display();

  delay(15000);

  Serial.println("Text demo");
  // large block of text
  display.clearBuffer();
  display.setTextSize(1);
  testdrawtext(
      "Lorem ipsum dolor sit amet, consectetur adipiscing elit. Curabitur "
      "adipiscing ante sed nibh tincidunt feugiat. Maecenas enim massa, "
      "fringilla sed malesuada et, malesuada sit amet turpis. Sed porttitor "
      "neque ut ante pretium vitae malesuada nunc bibendum. Nullam aliquet "
      "ultrices massa eu hendrerit. Ut sed nisi lorem. In vestibulum purus a "
      "tortor imperdiet posuere. ",
      EPD_BLACK);
  display.display();

  delay(15000);

  display.clearBuffer();
  for (int16_t i = 0; i < display.width(); i += 4) {
    display.drawLine(0, 0, i, display.height() - 1, EPD_BLACK);
  }

  for (int16_t i = 0; i < display.height(); i += 4) {
    display.drawLine(display.width() - 1, 0, 0, i, EPD_RED);
  }
  display.display();

  delay(15000); # 15 second delay before going into the next display
}

void testdrawtext(const char *text, uint16_t color) {
  display.setCursor(0, 0);
  display.setTextColor(color);
  display.setTextWrap(true);
  display.print(text);
}

- Note when this code ran
    - Multiple flickering inbetween display changes

- Other issues
    - The process can be confusing to have the ESP32 execute the code to the E-Ink
        - Things that worked
            - Have to select the USB port again after it compiles
            - Have to press the reset button on the ESP32

- EYESPI Breakout
    - https://learn.adafruit.com/adafruit-eyespi-breakout-board/pinouts
```

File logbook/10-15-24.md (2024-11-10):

# 10-15-24

## [Interface with HX711 and Load Cell IRL](https://github.com/BTrujillo816/coffee-scale/issues/14)

### Wiring from Load Cell to HX711

- Red wire to E+
- Black wire to E-
- Green wire to B+
- White wire t0 B-

### Wiring from HX711 to ESP32-S3

- VIN (Red wire) to 3V
- GND (Black wire) to GND
- DATA (Yellow wire) to GPIO8/A5
- SCK (Blue wire) to GPIO14/A4

### Library

- Adafruit_HX711 library

### HX711 Schematics

https://learn.adafruit.com/adafruit-hx711-24-bit-adc/downloads

### Example Code

```c++
#include "Adafruit_HX711.h"

// Define the pins for the HX711 communication
const uint8_t DATA_PIN = 2;  // Can use any pins!
const uint8_t CLOCK_PIN = 3; // Can use any pins!

Adafruit_HX711 hx711(DATA_PIN, CLOCK_PIN);

void setup() {
  Serial.begin(115200);

  // wait for serial port to connect. Needed for native USB port only
  while (!Serial) {
    delay(10);
  }

  Serial.println("Adafruit HX711 Test!");

  // Initialize the HX711
  hx711.begin();

  // read and toss 3 values each
  Serial.println("Tareing....");
  for (uint8_t t=0; t<3; t++) {
    hx711.tareA(hx711.readChannelRaw(CHAN_A_GAIN_128));
    hx711.tareA(hx711.readChannelRaw(CHAN_A_GAIN_128));
    hx711.tareB(hx711.readChannelRaw(CHAN_B_GAIN_32));
    hx711.tareB(hx711.readChannelRaw(CHAN_B_GAIN_32));
  }
} 

void loop() {
  // Read from Channel A with Gain 128, can also try CHAN_A_GAIN_64 or CHAN_B_GAIN_32
  // since the read is blocking this will not be more than 10 or 80 SPS (L or H switch)
  int32_t weightA128 = hx711.readChannelBlocking(CHAN_A_GAIN_128);
  Serial.print("Channel A (Gain 128): ");
  Serial.println(weightA128);

  // Read from Channel A with Gain 128, can also try CHAN_A_GAIN_64 or CHAN_B_GAIN_32
  int32_t weightB32 = hx711.readChannelBlocking(CHAN_B_GAIN_32);
  Serial.print("Channel B (Gain 32): ");
  Serial.println(weightB32);
}
```

### Issues

- Serial monitor always outputs zero even after applying pressure to the strain gauge

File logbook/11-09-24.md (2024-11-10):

# 11-09-24

## [Update "Stage 2: ADC" based on "Figure 4. Reference PCB Board Schematic"](https://github.com/BTrujillo816/coffee-scale/issues/19)

### General

- Updated Stage 1 and Stage 2 based on Figure 4 on HX711 datasheet

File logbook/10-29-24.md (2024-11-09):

# 10-29-24

## [Interface with OLED display IRL](https://github.com/BTrujillo816/coffee-scale/issues/17)

### Components

- [SPI OLED Display 128x32](https://www.adafruit.com/product/661)
- Arduino Uno

I followed this [Adafruit Guide](https://learn.adafruit.com/monochrome-oled-breakouts/wiring-128x32-spi-oled-display) to test the SPI OLED on an Arduino Uno.

This code can be found in [here](../software/ino/ssd1306_128x32_spi/ssd1306_128x32_spi.ino)

### Adafruit ESP32 Feather

- Load Cell: Successfully calibrated and now measures weight with acceptable tolerance
- OLED Display: Functions as intended when tested with example code
- Integration: Preliminary code to connect the load cell and OLED display
  - Code found [here](../software/ino/OLED_LoadCell_Code/Oled_LoadCell_Code.ino)
  - Result found [here](../logbook/10-30-24.assets/Result_Oled_LoadCell_Test.jpg) 

- Power/Wiring issues
  - OLED display or HX711 does not receive power at certain points along the power rail
    - This was evident when rewiring peripherals
    - As of right now, [this](../logbook/10-30-24.assets/Wiring.jpg) setup works
- Our known weight is a 60.3 grams [plier](../logbook/10-30-24.assets/Test_Weight.jpg)
  - The result is acceptable, as can be seen from this [image](../logbook/10-30-24.assets/Result_LoadCell_Test.png)

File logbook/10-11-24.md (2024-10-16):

# 10-11-24

## [Interface with eInk display using ESP32-S3 IRL](https://github.com/BTrujillo816/coffee-scale/issues/11)

- Installed "adafruit_EPD", "adafruit GFX", and "adafruit ImageReader" library from arduino
- From https://github.com/adafruit/Adafruit_EPD, I downloaded and moved the src folder to the arduino library folder

So far the example code I copied has finally compiled. Next goal is to try and change image in the display. However, will need to verify the pin connections again.

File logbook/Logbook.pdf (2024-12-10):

09-20-24

# Blink an LED with an ESP32 (https://github.com/BTrujillo816/coffee-scale/issues/6)

# Components

## ESP32-S3 resistor LED

# Notes

## Wokwi Project (https://wokwi.com/projects/409566066184866817)

I used this tutorial (https://makeabilitylab.github.io/physcomp/esp32/led-blink.html) to blink a singular LED on Wokwi

# Use ESP32 to interface with HX711 and Load Cell in Wokwi (https://github.com/BTrujillo816/coffee-scale/issues/7)

# Components

## ESP32-S3

HX711

## Load Cell

# Notes

## Wokwi Project (https://wokwi.com/projects/409582446772088833)

I used the Example Arduino Sketch from the Hobby Components forum post (https://forum.hobbycomponents.com/viewtopic.php?f=73&t=1763) by Andrew Davies

## I prefer this to using the HX711 Arduino library as I eventually want to learn how to

implement this in ESP-IDF using C.

## The HX711 datasheet contains a reference driver in both ASM and C

09-23-24
Interface with eInk Display using ESP32 on Wokwi (https://github.com/BTrujillo816/coffee-scale/issues/9)

# Details

## Status: Incomplete Hardware ESP32-S3

## ePaper 2.9" Software Wokwi

C++

# Notes

I cannot find an example Wokwi project using the Adafruit EDP Library (https://github.com/adafruit/Adafruit_EPD) that works properly

## The error seems to be with the GXEPD2 library

## I'll need to learn how to upload custom libraries It might be easier if I set up Wokwi for VS Code

# Start Project Schematic (https://github.com/BTrujillo816/coffee-scale/issues/10)

# Details

## Status: Incomplete Software

## KiCAD

# Notes

## We needed to make a custom symbol within KiCAD

## This can be found within I cannot figure out what electrical type MISO and MOSI should be

Related Forum Post (https://forum.kicad.info/t/electrical-type-for-spi-device-miso-pins/9444)
I think Adafruit really wants us to use a breakout board to interface with the eInk display

Error installing GxEPD2: Library install failed: testing local archive integrity: testing archive size: fetched archive size differs from size

## Without it, we'd have to solder headers onto the display if we wanted to use it on a breadboard

# Misc

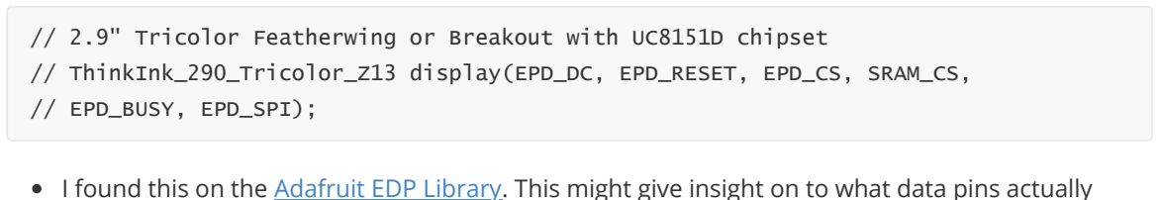
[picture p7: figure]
// EPD_BUSY, EPD_SPI);

I found this on the Adafruit EDP Library. (https://github.com/adafruit/Adafruit_EPD) This might give insight on to what data pins actually matter.

// 2.9" Tricolor Featherwing or Breakout with UC8151D chipset
// ThinkInk_290_Tricolor_Z13 display(EPD_DC, EPD_RESET, EPD_CS, SRAM_CS,

09-24-24

# Start Project Schematic (https://github.com/BTrujillo816/coffee-scale/issues/10)

# Details

## Status: Version 001 Hardware ESP32-S3

HX711

## Custom UC8151D Custom Strain Gauge

## MCP72831

# Wiring Guide

# Load Cell Wiring Guide to HX711

# HX711 to ESP32-S3

- E+ (red wire) stands for Excitation Positive of the load cell
- Connects to the Analog Voltage Supply Pin (AVDD/VIN) of the HX711
- E- (black ire) stands for Excitation Negative of the load cell
- Connects to the Analog Ground (AGND/GND) of the HX711
- A+ (white wire) stands for Signal Positive of the load cell
- Connects to the Positive Input for channel A (INA+ or A+) of the XH711
- A- (green wire) stands for Signal Negative of the load cell
- Connect to the Negative Input for channel A (INA- or A-) of the HX711

*** Important: Since no datasheet came with the acquired load cell. Assume manufacturer followed this convention.
1. Red Wire (E+): Positive excitation
2. Black Wire (E-): Negative excitation
3. White Wire (A+): Positive signal output
4. Green Wire (A-): Negative signal output

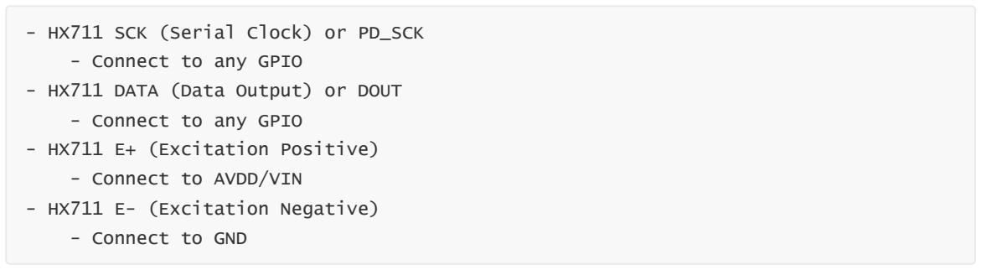
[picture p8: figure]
- HX711 SCK (Serial Clock) or PD_SCK; - Connect to any GPIO; - HX711 DATA (Data Output) or DOUT; - HX711 E+ (Excitation Positive); - Connect to AVDD/VIN; - HX711 E- (Excitation Negative); - Connect to GND

# ESP32 to E-ink Display

# Notes

ESP32-S3 has a lot more features than your standard ESP32. I am wondering if we should build this with an ESP32 instead of mounting on a ESP32-S3.

- Power Connections:
- VIN → Connect to 5V (or 3.3V, depending on your display’s requirement)
- 3.3V → Connect to VDD3P3 on the ESP32-S3
- GND → Connect to GND on the ESP32-S3
- SPI Connections:
- SCK → Connect to SCK of ESP32-S3 (GPIO36 on the ESP32-S3 Feather)
- MISO → Connect to MISO of ESP32-S3 (GPIO37 on the ESP32-S3 Feather)
- MOSI → Connect to MOSI of ESP32-S3 (GPIO35 on the ESP32-S3 Feather)
- ECS (Chip Select) → Connect to any GPIO
- D/C (Data/Command) → Connect to any GPIO
- SRCS (Source Select) → Connect to any GPIO
- SDCS (Data Chip Select) → Connect to any GPIO
- RST (Reset) → Connect to any GPIO
- BUSY → Connect to any GPIO
- ENA (Enable) → Connect to any GPIO

*** Necessary Pins for E-ink Display
- SCK: Required for clocking the data into the E-ink display.
- MISO: Typically used for data feedback from the E-ink display to the ESP32-S3. Not always necessary unless display requires it for certain operations (like reading status).
- MOSI: Essential for sending data from the ESP32-S3 to the E-ink display.
- ECS: This is important to tell the E-ink display when to listen to the data being sent. Without this, the display may not respond correctly.
- D/C : Important for distinguishing between data and command instructions sent to the display. It helps the display interpret what type of data it is receiving.
- RST: Often required to initialize the display. Without this, may not be able to reset the display or clear it properly.

*** Optional Pinks for E-ink Display
- BUSY: Indicates when the display is busy processing data. It's useful for synchronizing operations but may not be strictly necessary for all applications.
- SRCS: Might be used to select between different sources for data or power. Depending on your display.
- SDCS: Similar to ECS, this pin is likely used to select the data source. If display has both ECS and SDCS, check the documentation to see if both are necessary, as sometimes they can serve similar purposes.
- ENA: Typically enables or disables the display. It may be required to power on the display or enable certain functions. It's a common pin in various display modules.

Interface with eInk display using ESP32-S3 IRL (https://github.com/BTrujillo816/coffee-scale/issues/11)

# Details

## Status: Incomplete Hardware: Adafruit ESP32-S3 Feather

R: 220

## LED (Red)

# Soldering Headers

In order to breadboard with these components, we had to solder headers onto the ESP32-S3,

## EYESPI Breakout Board, and HX711 breakout board

HX711

## Might need to reflow some solder joints

# Notes

## In order to solve this error, I have attempted the following:

## Uninstalled and reinstalled Arduino IDE

Downloaded and installed CP210x USB to UART Bridge VCP Drivers from here (https://www.silabs.com/developers/usb-to-uart-bridge-vcp-drivers?tab=downloads)

## Restarted my computer multiple times Swapped USB-C cable

A fatal error occurred: Could not open COM6, the port doesn't exist Failed uploading: uploading error: exit status 2

10-02-24

# Blink LED IRL (https://github.com/BTrujillo816/coffee-scale/issues/13)

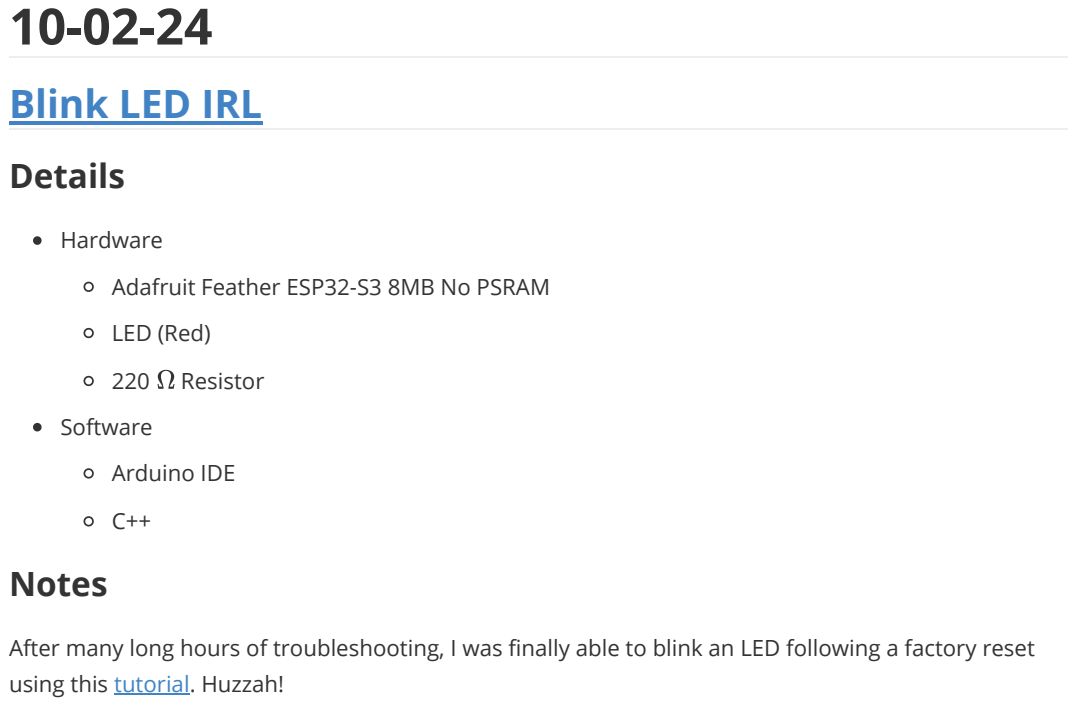
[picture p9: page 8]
Details

Hardware
Adafruit Feather ESP32-S3 8MB No PSRAM
LED (Red)
220 Resistor
Software
Arduino IDE
Notes

After many long hours of troubleshooting, I was finally able to blink an LED following a factory reset
using this tutorial. (https://learn.adafruit.com/adafruit-esp32-s3-feather/factory-reset) Huzzah!

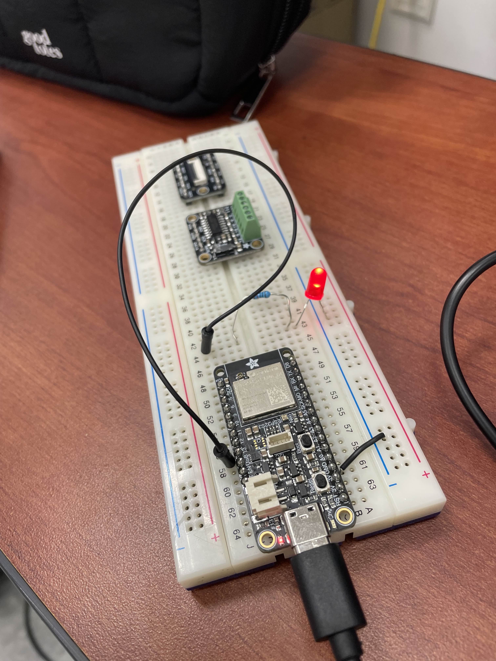
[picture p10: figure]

10-08-24

# Create a Nice Readable Schematic (https://github.com/BTrujillo816/coffee-scale/issues/16)

# Rules/Conventions

## Signals should flow from left to right PWR on top, GND always down

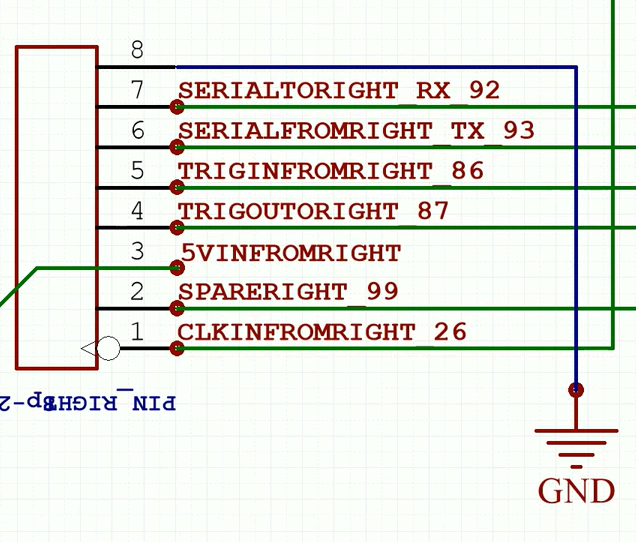
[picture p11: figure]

## Lines should never be on an angle

## Up, down, left, right Never, ever have lines going through your chip symbols Annotations should be horizontal

## The person shouldn't have to tilt their head to read them

Designators and their values can either be together on one side, or on opposite sides of a symbol

## Just make sure you are consistent

## Set pins to snap grid when creating symbols No need to show footprints on schematic Net name should be on top of netlist/lines Don't assign nets to things that have ports (+3V3 net when you have a 3V3 port)

## Avoid crossing wires if possible Edit symbol to move pins even if it doesn't match the physical layout

## Don't label nets if you are not going to use them

Signify if a symbol is going out to prevent confusion (someone might think it's a completed

## circuit)

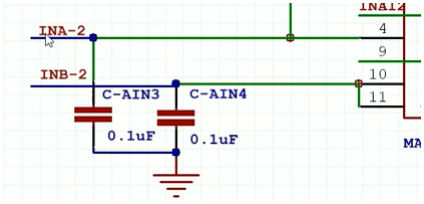
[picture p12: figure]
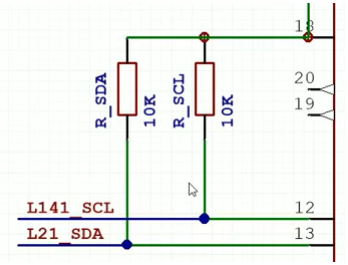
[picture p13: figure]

## Don't run wires through the schematic if you don't have to

Connectors don't have to be next to the components; however, you must properly label the nets

## Net names should be meaningful and nonredundant

Either change the symbol to all match the physical in mapping or group them up by functionality

## so that they support signal flow

If you edit for symbol flow, make sure that the inputs are on the left and outputs are on the

## right Be consistent with schematic symbols i.e. for capacitors, resistors Do not use decimal points for values in your schematic 0.01uF > 100nF or 100n

## Use ports for outputs Label sections with notes Make LEDS and other symbols vertical

## Don't create four way junctions off a single node

## Designators can be renamed if you truly need to but keep it short and sweet Use A4 schematic size since we're yankees

10-11-24
Interface with eInk display using ESP32-S3 IRL (https://github.com/BTrujillo816/coffee-scale/issues/11)

## Installed "adafruit_EPD", "adafruit GFX", and "adafruit ImageReader" library from arduino

From https://github.com/adafruit/Adafruit_EPD, I downloaded and moved the src folder to the

## arduino library folder

So far the example code I copied has finally compiled. Next goal is to try and change image in the display. However, will need to verify the pin connections again.

10-13-24
Interface with eInk display using ESP32-S3 IRL (https://github.com/BTrujillo816/coffee-scale/issues/11)

# Example Code for E-Ink from Adafruit

#include "Adafruit_ThinkInk.h"

#define EPD_DC 10

#define EPD_CS 5

#define EPD_BUSY -1 // can set to -1 to not use a pin (will wait a fixed delay) #define SRAM_CS 11

#define EPD_RESET 9 // can set to -1 and sh\are with microcontroller Reset! #define EPD_SPI &SPI // primary SPI

ThinkInk_290_Tricolor_Z13 display(EPD_DC, EPD_RESET, EPD_CS, SRAM_CS, EPD_BUSY, EPD_SPI);

void setup() {
Serial.begin(115200);
while (!Serial) {
delay(10);
}
Serial.println("Adafruit EPD full update test in red/black/white"); display.begin(THINKINK_TRICOLOR);
}

void loop() {
Serial.println("Banner demo");
display.clearBuffer();
display.setTextSize(3);
display.setCursor((display.width() - 144) / 2, (display.height() - 24) / 2); display.setTextColor(EPD_BLACK);
display.print("Tri");
display.setTextColor(EPD_RED);
display.print("Color");
display.display();

delay(15000);

Serial.println("Color rectangle demo"); display.clearBuffer();
display.fillRect(display.width() / 3, 0, display.width() / 3,
| display.height(), EPD_BLACK);
display.fillRect((display.width() * 2) / 3, 0, display.width() / 3,
| display.height(), EPD_RED);
display.display();

delay(15000);

Serial.println("Text demo"); // large block of text
display.clearBuffer();
display.setTextSize(1);
testdrawtext(
"Lorem ipsum dolor sit amet, consectetur adipiscing elit. Curabitur " "adipiscing ante sed nibh tincidunt feugiat. Maecenas enim massa, " "fringilla sed malesuada et, malesuada sit amet turpis. Sed porttitor " "neque ut ante pretium vitae malesuada nunc bibendum. Nullam aliquet " "ultrices massa eu hendrerit. Ut sed nisi lorem. In vestibulum purus a " "tortor imperdiet posuere. ",
EPD_BLACK);
display.display();

delay(15000);

display.clearBuffer();
for (int16_t i = 0; i < display.width(); i += 4) { display.drawLine(0, 0, i, display.height() - 1, EPD_BLACK); }

for (int16_t i = 0; i < display.height(); i += 4) { display.drawLine(display.width() - 1, 0, 0, i, EPD_RED); }
display.display();

delay(15000); # 15 second delay before going into the next display }

void testdrawtext(const char *text, uint16_t color) { display.setCursor(0, 0);
display.setTextColor(color); display.setTextWrap(true);
display.print(text);
}
- Note when this code ran
- Multiple flickering inbetween display changes
- Other issues
- The process can be confusing to have the ESP32 execute the code to the E-Ink
- Things that worked
- Have to select the USB port again after it compiles
- Have to press the reset button on the ESP32
- EYESPI Breakout
- https://learn.adafruit.com/adafruit-eyespi-breakout-board/pinouts

10-15-24
Interface with HX711 and Load Cell IRL (https://github.com/BTrujillo816/coffee-scale/issues/14)

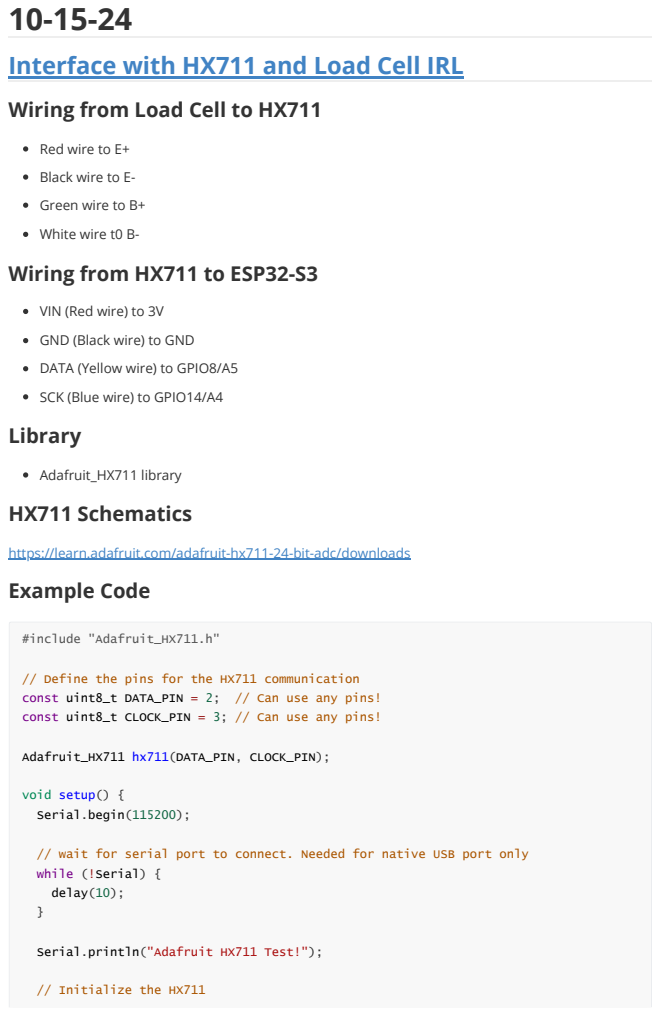
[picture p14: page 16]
Adafruit_HX711 library HX711 Schematics; #include "Adafruit_HX711.h"; const uint8_t DATA_PIN = 2;; // Can use any pins!; Adafruit_HX711 hx711(DATA_PIN, CLOCK_PIN);; void setup() {; Serial.begin(115200);; // Initialize the HX711

Wiring from Load Cell to HX711

Red wire to E+
Black wire to E-
Green wire to B+
White wire t0 B-
Wiring from HX711 to ESP32-S3

VIN (Red wire) to 3V
GND (Black wire) to GND
DATA (Yellow wire) to GPIO8/A5
SCK (Blue wire) to GPIO14/A4
Library

https://learn.adafruit.com/adafruit-hx711-24-bit-adc/downloads
Example Code

// Define the pins for the HX711 communication
const uint8_t CLOCK_PIN = 3; // Can use any pins!

// wait for serial port to connect. Needed for native USB port only
while (!Serial) {
delay(10);

Serial.println("Adafruit HX711 Test!");

# Issues

## Serial monitor always outputs zero even after applying pressure to the strain gauge

hx711.begin();

// read and toss 3 values each Serial.println("Tareing....");
for (uint8_t t=0; t<3; t++) { hx711.tareA(hx711.readChannelRaw(CHAN_A_GAIN_128)); hx711.tareA(hx711.readChannelRaw(CHAN_A_GAIN_128)); hx711.tareB(hx711.readChannelRaw(CHAN_B_GAIN_32)); hx711.tareB(hx711.readChannelRaw(CHAN_B_GAIN_32)); }
}

void loop() {
// Read from Channel A with Gain 128, can also try CHAN_A_GAIN_64 or CHAN_B_GAIN_32
// since the read is blocking this will not be more than 10 or 80 SPS (L or H switch)
int32_t weightA128 = hx711.readChannelBlocking(CHAN_A_GAIN_128); Serial.print("Channel A (Gain 128): ");
Serial.println(weightA128);

// Read from Channel A with Gain 128, can also try CHAN_A_GAIN_64 or CHAN_B_GAIN_32
int32_t weightB32 = hx711.readChannelBlocking(CHAN_B_GAIN_32); Serial.print("Channel B (Gain 32): ");
Serial.println(weightB32);
}

10-16-24

# Setup Wokwi for VS Code (https://github.com/BTrujillo816/coffee-scale/issues/12)

I was able to setup Wokwi for VS Code using Wokwi's Guide. (https://docs.wokwi.com/vscode/getting-started/) I'm interested in exploring PlatformIO as an IDE for programming the physical ESP32-S3 itself.

10-22-24
Interface with HX711 and Load Cell IRL (https://github.com/BTrujillo816/coffee-scale/issues/14)

# Adafruit Example Code

#include <Arduino.h>

#include "HX711.h"

// HX711 circuit wiring
const int LOADCELL_DOUT_PIN = 9; const int LOADCELL_SCK_PIN = 8;

HX711 scale;

void setup() {
Serial.begin(57600);
Serial.println("HX711 Demo"); Serial.println("Initializing the scale");

scale.begin(LOADCELL_DOUT_PIN, LOADCELL_SCK_PIN);

Serial.println("Before setting up the scale:");
Serial.print("read: \t\t");
Serial.println(scale.read()); | // print a raw reading from the ADC

Serial.print("read average: \t\t");
Serial.println(scale.read_average(20)); // print the average of 20 readings from the ADC

Serial.print("get value: \t\t");
Serial.println(scale.get_value(5)); // print the average of 5 readings from the ADC minus the tare weight (not set yet)

Serial.print("get units: \t\t");
Serial.println(scale.get_units(5), 1); // print the average of 5 readings from the ADC minus tare weight (not set) divided
// by the SCALE parameter (not set yet)

scale.set_scale(765);
//scale.set_scale(-471.497); | // this value is obtained by
calibrating the scale with known weights; see the README for details
scale.tare(); | // reset the scale to 0

Serial.println("After setting up the scale:");

Serial.print("read: \t\t");
Serial.println(scale.read()); | // print a raw reading from the ADC

Serial.print("read average: \t\t");

# Random Nerd Tutorials Code

Serial.println(scale.read_average(20)); | // print the average of 20 readings
from the ADC

Serial.print("get value: \t\t");
Serial.println(scale.get_value(5)); // print the average of 5 readings from the ADC minus the tare weight, set with tare()

Serial.print("get units: \t\t");
Serial.println(scale.get_units(5), 1); | // print the average of 5 readings
from the ADC minus tare weight, divided
// by the SCALE parameter set with set_scale

Serial.println("Readings:");
}

void loop() {
Serial.print("one reading:\t"); Serial.print(scale.get_units(), 1); Serial.print("\t| average:\t"); Serial.println(scale.get_units(10), 5);

delay(5000);
}

/*
Rui Santos
Complete project details at https://RandomNerdTutorials.com/arduino-load-cell-hx711/

Permission is hereby granted, free of charge, to any person obtaining a copy of this software and associated documentation files.

The above copyright notice and this permission notice shall be included in all copies or substantial portions of the Software.
*/

// Calibrating the load cell
#include "HX711.h"

// HX711 circuit wiring
const int LOADCELL_DOUT_PIN = 2; const int LOADCELL_SCK_PIN = 3;

HX711 scale;

void setup() {
Serial.begin(57600);
scale.begin(LOADCELL_DOUT_PIN, LOADCELL_SCK_PIN); }

# Notes

## The test code from adafruit library was not working as intended The output is either 0 or some constant value that does not change no matter how much pressure is applied to the gauge

void loop() {

if (scale.is_ready()) {
scale.set_scale();
Serial.println("Tare... remove any weights from the scale."); delay(5000);
scale.tare();
Serial.println("Tare done...");
Serial.print("Place a known weight on the scale..."); delay(5000);
long reading = scale.get_units(10); Serial.print("Result: ");
Serial.println(reading);
}
else {
Serial.println("HX711 not found."); }
delay(1000);
}

//calibration factor will be the (reading)/(known weight)

10-29-24

# Interface with OLED display IRL (https://github.com/BTrujillo816/coffee-scale/issues/17)

# Components

## SPI OLED Display 128x32 (https://www.adafruit.com/product/661) Arduino Uno

I followed this Adafruit Guide (https://learn.adafruit.com/monochrome-oled-breakouts/wiring-128x32-spi-oled-display) to test the SPI OLED on an Arduino Uno.

## This code can be found in here

# Adafruit ESP32 Feather

## Load Cell: Successfully calibrated and now measures weight with acceptable tolerance OLED Display: Functions as intended when tested with example code

## Integration: Preliminary code to connect the load cell and OLED display Code found here Result found here

## Power/Wiring issues OLED display or HX711 does not receive power at certain points along the power rail This was evident when rewiring peripherals

## As of right now, this setup works Our known weight is a 60.3 grams plier The result is acceptable, as can be seen from this image

10-30-24
Update schematic to include OLED display (https://github.com/BTrujillo816/coffee-scale/issues/18)

# General

Added OLED (SSD1306) datasheet (http://../coffee-scale/documentation/assets/SSD1306.pdf) to documentation branch

# Eagle File to KiCAD

## Why does Adafruit only offer Eagle files :c

# Symbol Creation

## Figured out that we don't need it anyways Added 08x02 connectors to socket display

# Make a Nice Readable Schematic (https://github.com/BTrujillo816/coffee-scale/issues/16)

# LiPo Battery Charger

Replaced SparkFun ESP32 Thing circuit with prettier circuit from Adafruit ESP32-S3 Feather

# Power and Filtering

## Changed custom JST connector to boring KiCAD 01x02 connector I should place this on the left side to have it function clearly as an input

# Load Cell

## Edited symbol so no wires crisscross

# ADC

## Added No Connect flags

# Microcontroller

## Added No Connect flags

# Display

## Made wiring nice and pretty Added text I should add more text about the actual display

11-09-24

# Update "Stage 2: ADC" based on "Figure 4. Reference PCB Board Schematic" (https://github.com/BTrujillo816/coffee-scale/issues/19)

# General

## Updated Stage 1 and Stage 2 based on Figure 4 on HX711 datasheet

11-12-24
Add USB-C receptacle to schematic (https://github.com/BTrujillo816/coffee-scale/issues/24)

# General

## Added USB-C receptable

Read this article (https://dubiouscreations.com/2021/04/06/designing-with-usb-c-lessons-learned/) to learn more about reasoning behind design

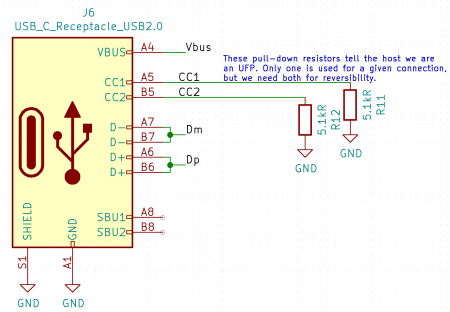
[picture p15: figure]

11-13-24

# Add pushbuttons to prototype (https://github.com/BTrujillo816/coffee-scale/issues/25)

## Added three button to do three different functionalities Tare feature to zero the scale after putting weight when button is pressed

## Timer function that starts to count and show on the OLED display when the button is pressed

## Wake up Added an active buzzer for sound effects

# Configure Deep Sleep mode (https://github.com/BTrujillo816/coffee-scale/issues/23)

Added a deep sleep mode by following this website (https://randomnerdtutorials.com/esp32-deep-sleep-arduino-ide-wake-up-sources/)

## Currently, the threshold weight for deep sleep is <1g

Create flow rate display algorithm (https://github.com/BTrujillo816/coffee-scale/issues/20)

## Although this works, we still need to figure out a better method of testing

Run tests on breadboard prototype (https://github.com/BTrujillo816/coffee-scale/issues/26)

## Tested the core functionalities of our prototype for our midterm presentation

More details can be found in our testing document (https://github.com/BTrujillo816/coffee-scale/blob/main/documentation/TestDocument.md)

## Scale Accuracy Test Benchmarked three different objects to determine the scale's accuracy

## Precision Test Weighed the same object multiple times to determine consistency Timer

## Ran a known timer at the same time to determine accuracy Deep sleep timer

Tested deep sleep timer by letting an object rest for more than 30 seconds, removing it, and

## then waiting

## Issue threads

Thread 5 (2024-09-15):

Add esp32-thing's Lithium Polymer Battery circuit to PCB schematic

BTrujillo816, 2024-09-15:
[esp32-thing-schematic.pdf](https://github.com/user-attachments/files/17007060/esp32-thing-schematic.pdf)

Closed 2024-09-24.

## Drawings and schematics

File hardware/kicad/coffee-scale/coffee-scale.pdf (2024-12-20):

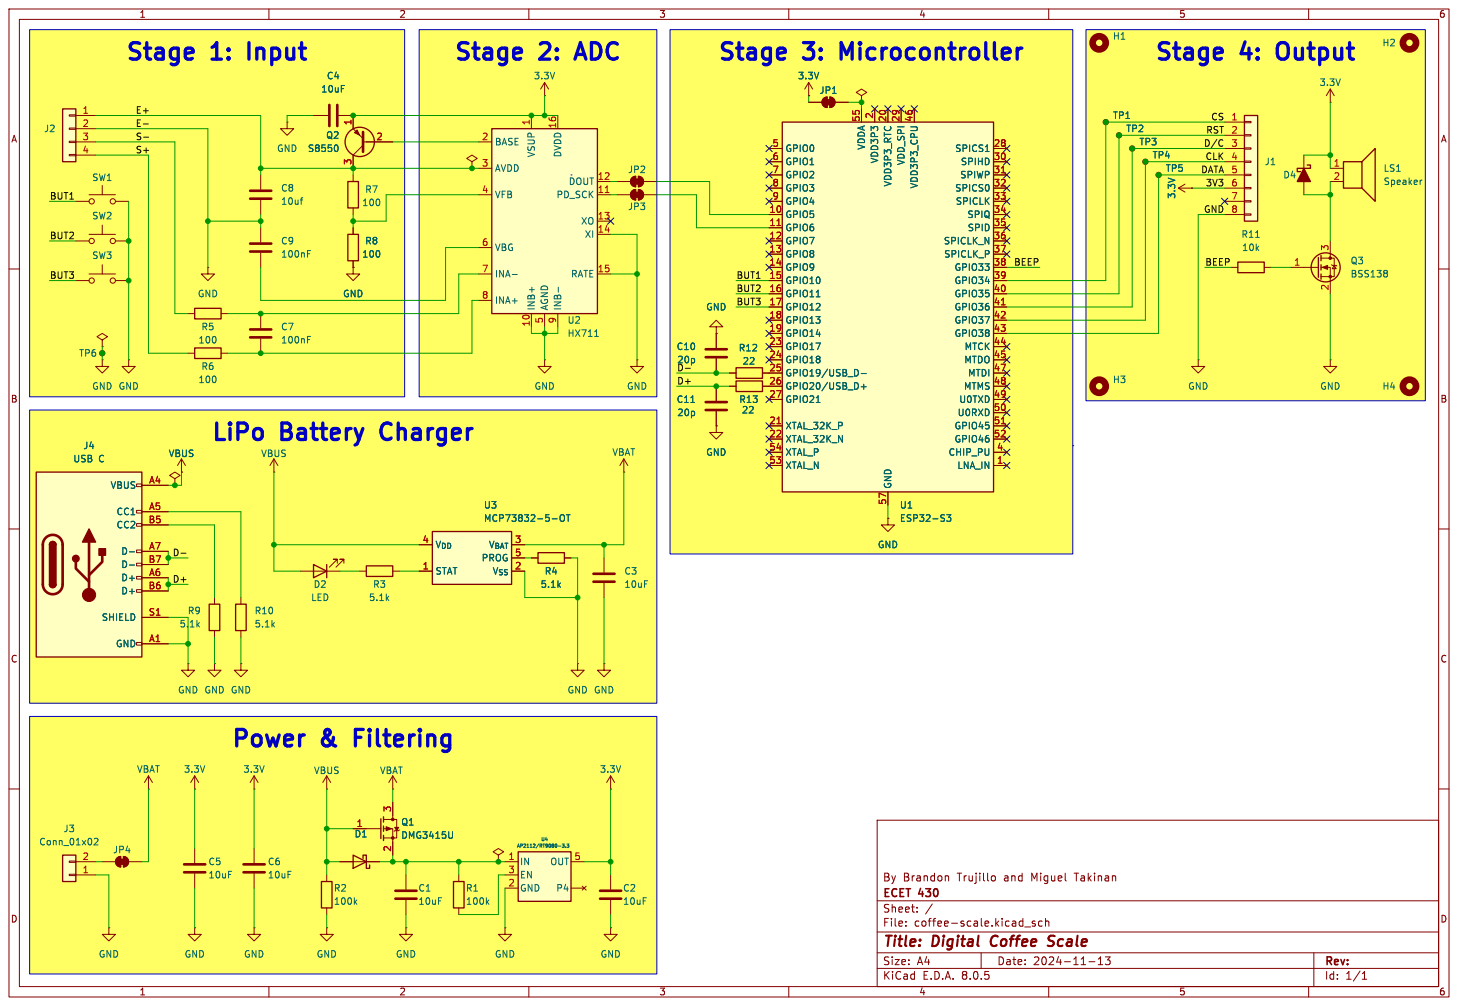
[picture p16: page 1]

1 INB+ 10 PD_SCK 11 DOUT 12 XO 13 XI 14 RATE 15 DVDD 16 BASE 2 AVDD 3 VFB 4 AGND

2 VDD3P3_RTC 20 XTAL_32K_P 21 XTAL_32K_N 22 GPIO17 23 GPIO18 24 GPIO19/USB_D- 25 GPIO20/USB_D+ 26 GPIO21 27 SPICS1 28 VDD_SPI 29 SPIHD 30 SPIWP 31 SPICS0 32 SPICLK 33 SPIQ 34 SPID 35 SPICLK_P 37 GPIO33 38 GPIO34 39 CHIP_PU 4 GPIO35 40 GPIO36 41 GPIO37 42 GPIO38 43 MTCK 44 VDD3P3_CPU 46 MTDI 47 MTMS 48 U0TXD 49 GPIO0 5 U0RXD 50 GPIO46 52 XTAL_N 53 XTAL_P 54 VDDA 55 GND 57 GPIO1 6 GPIO2 7 GPIO3 8 GPIO4 9 U1ESP32-S3 GND

2 VDD3P3_RTC 20 XTAL_32K_P 21 XTAL_32K_N 22 GPIO17 23 GPIO18 24 GPIO19/USB_D- 25 GPIO20/USB_D+ 26 GPIO21 27 SPICS1 28 VDD_SPI 29 SPIHD 30 SPIWP 31 SPICS0 32 SPICLK 33 SPIQ 34 SPID 35 SPICLK_P 37 GPIO33 38 GPIO34 39 CHIP_PU 4 GPIO35 40 GPIO36 41 GPIO37 42 GPIO38 43 MTCK 44 VDD3P3_CPU 46 MTDI 47 MTMS 48 U0TXD 49 GPIO0 5 U0RXD 50 GPIO46 52 XTAL_N 53 XTAL_P 54 VDDA 55 GND 57 GPIO1 6 GPIO2 7 GPIO3 8 GPIO4 9 GND

Id: 1/1 Title: Digital Coffee Scale

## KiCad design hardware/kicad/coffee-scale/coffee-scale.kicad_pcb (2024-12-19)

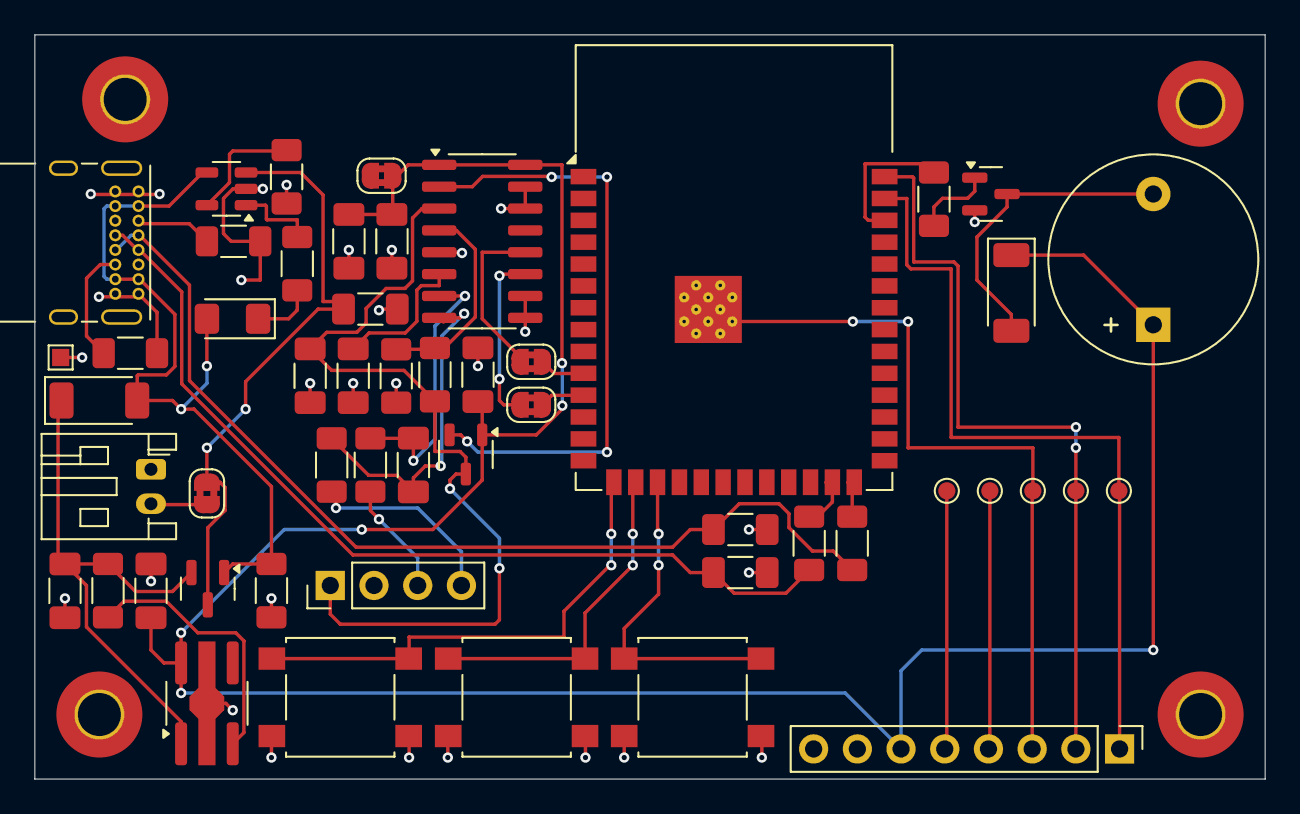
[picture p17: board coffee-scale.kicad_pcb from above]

Board: 2 copper layers, 71.5 x 43.2 mm, 56 parts (0 on the bottom side), 39 nets.

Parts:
C1, C2, C3, C4, C5, C6: 10uF; C_1206_3216Metric_Pad1.33x1.80mm_HandSolder
C7, C9: 100nF; C_1206_3216Metric_Pad1.33x1.80mm_HandSolder
C8: 10uf; C_1206_3216Metric_Pad1.33x1.80mm_HandSolder
C10, C11: 20p; C_1206_3216Metric_Pad1.33x1.80mm_HandSolder
D1: D_SOD-128
D2: LED; LED_1206_3216Metric_Pad1.42x1.75mm_HandSolder
D4: D_Schottky_Filled; D_SOD-128
H1, H2, H3, H4: MountingHole; MountingHole_2.5mm_Pad_TopBottom
J1: Conn_01x08; PinHeader_1x08_P2.54mm_Vertical
J2: Conn_01x04; PinHeader_1x04_P2.54mm_Vertical
J3: Conn_01x02; JST_PH_S2B-PH-K_1x02_P2.00mm_Horizontal
J4: USB C; USB_C_Receptacle_GCT_USB4085
JP1, JP2, JP3, JP4: SolderJumper_2_Bridged; SolderJumper-2_P1.3mm_Bridged2Bar_RoundedPad1.0x1.5mm
LS1: Speaker; Buzzer_12x9.5RM7.6
Q1: DMG3415U; SOT-23
Q2: S8550; SOT-23-3
Q3: BSS138; SOT-23
R1, R2: 100k; R_1206_3216Metric_Pad1.30x1.75mm_HandSolder
R3, R4, R9, R10: 5.1k; R_1206_3216Metric_Pad1.30x1.75mm_HandSolder
R5, R6, R7, R8: 100; R_1206_3216Metric_Pad1.30x1.75mm_HandSolder
R11: 10k; R_1206_3216Metric_Pad1.30x1.75mm_HandSolder
R12, R13: 22; R_1206_3216Metric_Pad1.30x1.75mm_HandSolder
SW1, SW2, SW3: SW_Push; SW_SPST_B3S-1000
TP1, TP2, TP3, TP4, TP5: TestPoint_Small; TestPoint_Pad_D1.0mm
TP6: TestPoint_Small; TestPoint_Pad_1.0x1.0mm
U1: ESP32-S3; ESP32-S3-WROOM-1
U2: HX711; SOP-16_3.9x9.9mm_P1.27mm
U3: MCP73832-5-OT; SOT-23-5
U4: AP2112/RT9080-3.3; SOT-89-5_Handsoldering

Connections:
3.3V: C2.1, C4.1, C5.1, C6.1, D4.1 (K), J1.6, JP1.1 (A), LS1.1, Q2.1 (E), U2.1 (VSUP), U2.16 (DVDD), U4.5 (OUT)
/BEEP: R11.2, U1.38 (GPIO33)
/BUT1: SW1.1, U1.15 (GPIO10)
/BUT2: SW2.1, U1.16 (GPIO11)
/BUT3: SW3.1, U1.17 (GPIO12)
/CLK: J1.4, TP4.1
/CS: J1.1, TP1.1, U1.39 (GPIO34)
/D+: C11.1, J4.A6 (D+), J4.B6 (D+), R13.1
/D-: C10.2, J4.A7 (D-), J4.B7 (D-), R12.2
/DATA: J1.5, TP5.1
/D/C: J1.3, TP3.1, U1.41 (GPIO36)
/E+: C8.1, J2.1, Q2.3 (C), R7.2, U2.3 (AVDD)
/RST: J1.2, TP2.1, U1.40 (GPIO35)
/S+: J2.4, R6.1
/S-: J2.3, R5.1
GND: C1.2, C2.2, C3.2, C4.2, C5.2, C6.2, C8.2, C9.1, C10.1, C11.2, J1.8, J2.2, J3.1, J4.A1 (GND), J4.A12 (GND), J4.B1 (GND), J4.B12 (GND), J4.S1 (SHIELD), Q3.2 (S), R2.2, R4.2, R8.1, R9.2, R10.2, SW1.2, SW2.2, SW3.2, TP6.1, U2.5 (AGND), U2.9 (INB-), U2.10 (INB+), U2.14 (XI), U2.15 (RATE), U3.2 (V_{SS}), U4.2 (GND)
unnamed: C1.1, D1.1 (K), Q1.2 (S), R1.1, U4.1 (IN)
unnamed: D2.1 (K), R3.1
unnamed: D4.2 (A), LS1.2, Q3.3 (D)
unnamed: J3.2, JP4.1 (A)
unnamed: J4.A5 (CC1), R10.1
unnamed: J4.B5 (CC2), R9.1
unnamed: JP2.1 (A), U2.12 (DOUT)
unnamed: JP2.2 (B), U1.10 (GPIO5)
unnamed: JP3.1 (A), U1.11 (GPIO6)
unnamed: JP3.2 (B), U2.11 (PD_SCK)
unnamed: Q2.2 (B), U2.2 (BASE)
unnamed: Q3.1 (G), R11.1
unnamed: R12.1, U1.25 (GPIO19/USB_D-)
unnamed: R13.2, U1.26 (GPIO20/USB_D+)
unnamed: C7.2, R6.2, U2.8 (INA+)
unnamed: C7.1, R5.2, U2.7 (INA-)
unnamed: C9.2, U2.6 (VBG)
unnamed: R7.1, R8.2, U2.4 (VFB)
unnamed: R4.1, U3.5 (PROG)
unnamed: R3.2, U3.1 (STAT)
unnamed: R1.2, U4.3 (EN)
VBAT: C3.1, JP4.2 (B), Q1.3 (D), U3.3 (V_{BAT})
VBUS: D1.2 (A), D2.2 (A), J4.A4 (VBUS), J4.A9 (VBUS), J4.B4 (VBUS), J4.B9 (VBUS), Q1.1 (G), R2.1, U3.4 (V_{DD})

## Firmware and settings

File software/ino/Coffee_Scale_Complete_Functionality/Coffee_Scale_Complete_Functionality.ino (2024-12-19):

#include <SPI.h>
#include <Wire.h>
#include <Adafruit_GFX.h>
#include <Adafruit_SSD1306.h>
#include "HX711.h"
#include "driver/rtc_io.h"
#include "esp_sleep.h"

// OLED display settings
#define SCREEN_WIDTH 128
#define SCREEN_HEIGHT 32
#define OLED_MOSI  11
#define OLED_CLK   10
#define OLED_DC    9
#define OLED_CS    5
#define OLED_RESET 6

Adafruit_SSD1306 display(SCREEN_WIDTH, SCREEN_HEIGHT, OLED_MOSI, OLED_CLK, OLED_DC, OLED_RESET, OLED_CS);

// HX711 circuit wiring
const int LOADCELL_DOUT_PIN = 17;
const int LOADCELL_SCK_PIN = 18;

HX711 scale;

// Button pins
const int buttonTarePin = 16;  // Button 1: Tare
const int buttonTimerPin = 15; // Button 2: Timer Start/Stop
const int buzzerPin = 14;      // Active buzzer pin
const int wakeUpPin = 12;      // GPIO 12 for wake-up

// Variables
unsigned long previousMillis = 0;  // Timer
unsigned long interval = 1000;      // 1 second interval for the timer
bool timerRunning = false;          // Timer state
unsigned long timerStartMillis = 0; // Timer start time
unsigned long lastActivityMillis = 0; // Last activity time
const unsigned long sleepTimeout = 30000; // 30 seconds timeout for sleep

RTC_DATA_ATTR int bootCount = 0; // Keep track of reboots during deep sleep

// Flow rate variables
float lastWeight = 0.0;
float flowRate = 0.0;
unsigned long lastFlowTime = 0;
float lastDisplayWeight = 0.0;

void setup() {
  // Initialize Serial Monitor
  Serial.begin(57600);
  delay(1000);
  Serial.println("HX711 Demo");

  // Wake-up cause check
  print_wakeup_reason();

  // Initialize the display and scale
  initializeDisplay();
  initializeScale();

  // Initialize buttons and buzzer
  pinMode(buttonTarePin, INPUT_PULLUP);
  pinMode(buttonTimerPin, INPUT_PULLUP);
  pinMode(buzzerPin, OUTPUT);

  // Configure wakeup source on GPIO 12
  esp_sleep_enable_ext0_wakeup(GPIO_NUM_12, 1); // Wake up when GPIO 12 is HIGH

  // Track activity start
  lastActivityMillis = millis();
}

void loop() {
  // Read weight from scale
  float weight = scale.get_units(10);

  // Flow rate calculation (grams per second)
  unsigned long currentMillis = millis();
  if (currentMillis - lastFlowTime >= 1000) {  // Update every second
    flowRate = abs(weight - lastWeight);  // Flow rate is the difference in weight over 1 second
    lastWeight = weight;  // Save the current weight for the next calculation
    lastFlowTime = currentMillis;
  }
  
  // Don't go to sleep if the weight is above 1 gram or if the timer is running
  if ((weight > 1 || timerRunning)) {
    lastActivityMillis = millis(); // Reset activity timer when weight is detected or timer is running
  }

  // Check if Tare button is pressed
  if (digitalRead(buttonTarePin) == LOW) {
    scale.tare();  // Reset the scale to 0
    beep();
    displayMessage("Scale Tared");
    delay(500); // Debounce time to prevent multiple readings
    lastActivityMillis = millis(); // Reset activity timer
  }

  // Check if Timer button is pressed
  if (digitalRead(buttonTimerPin) == LOW) {
    if (!timerRunning) {
      timerRunning = true;
      timerStartMillis = millis();
      beep();
      displayMessage("Timer Started");
    } else {
      timerRunning = false;
      beep();
      displayMessage("Timer Stopped");
    }
    delay(500); // Debounce time to prevent multiple readings
    lastActivityMillis = millis(); // Reset activity timer
  }

  // Display the weight
  display.clearDisplay();
  display.setCursor(0, 0);
  display.print("Weight: ");
  if (weight > 1.0){
    if (flowRate > 0.3){
    display.print(weight, 1);  // Display weight with 1 decimal place
    lastDisplayWeight = weight;
    }
    else{
      display.print(lastDisplayWeight, 1);
    }
  }
  else{
    display.print(0.0, 1);
  }
  display.print(" g");

  // Display flow rate (grams per second)
  display.setCursor(0, 16);
  display.print("Flow Rate: ");
  if (flowRate > 0.5){
    display.print(flowRate, 1);  // Display flow rate with 2 decimal places
  }
    else{
      display.print(0.0, 1);
    }
  display.print(" g/s");

  // Display the timer if running
  if (timerRunning) {
    unsigned long elapsedTime = millis() - timerStartMillis;
    unsigned long seconds = elapsedTime / 1000;
    display.setCursor(0, 24);
    display.print("Timer: ");
    display.print(seconds);
    display.print(" s");
  }

  // Show the display buffer on the screen
  display.display();
  delay(100);  // Delay between screen updates
  
  // Check for sleep timeout if no weight or activity is detected
  if (weight <= 1 && !timerRunning && millis() - lastActivityMillis > sleepTimeout) {
    goToSleep();
  }
}

// Function to initialize the OLED display
void initializeDisplay() {
  if (!display.begin(SSD1306_SWITCHCAPVCC)) {
    Serial.println(F("SSD1306 allocation failed"));
    for (;;); // Stop if OLED initialization fails
  }
  display.clearDisplay();
  display.setTextSize(1);
  display.setTextColor(SSD1306_WHITE);
  display.setCursor(0, 0);
  display.display(); // Show initial buffer
}

// Function to initialize the scale
void initializeScale() {
  scale.begin(LOADCELL_DOUT_PIN, LOADCELL_SCK_PIN);
  scale.set_scale(25924 / 60.2);  // Set scale factor (adjust to your scale)
  scale.tare();  // Reset the scale to 0
}

// Function to display a short message on the OLED
void displayMessage(String message) {
  display.clearDisplay();
  display.setCursor(0, 0);
  display.setTextSize(1);
  display.print(message);
  display.display();
}

// Function to play a beep sound using the active buzzer
void beep() {
  digitalWrite(buzzerPin, HIGH);  // Turn the buzzer ON
  delay(100);                     // Wait for 100 milliseconds
  digitalWrite(buzzerPin, LOW);   // Turn the buzzer OFF
}

// Function to go to deep sleep
void goToSleep() {
  Serial.println("Going to sleep now");
  delay(100);  // Allow serial output to complete

  // Enter deep sleep
  esp_deep_sleep_start();
}

// Function to print the reason for wake-up
void print_wakeup_reason() {
  esp_sleep_wakeup_cause_t wakeup_reason = esp_sleep_get_wakeup_cause();
  switch (wakeup_reason) {
    case ESP_SLEEP_WAKEUP_EXT0: Serial.println("Wakeup caused by external signal using RTC_IO"); break;
    case ESP_SLEEP_WAKEUP_TIMER: Serial.println("Wakeup caused by timer"); break;
    default: Serial.printf("Wakeup was not caused by deep sleep: %d\n", wakeup_reason); break;
  }
}

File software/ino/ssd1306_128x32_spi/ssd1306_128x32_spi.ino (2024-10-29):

/**************************************************************************
 This is an example for our Monochrome OLEDs based on SSD1306 drivers

 Pick one up today in the adafruit shop!
 ------> http://www.adafruit.com/category/63_98

 This example is for a 128x32 pixel display using SPI to communicate
 4 or 5 pins are required to interface.

 Adafruit invests time and resources providing this open
 source code, please support Adafruit and open-source
 hardware by purchasing products from Adafruit!

 Written by Limor Fried/Ladyada for Adafruit Industries,
 with contributions from the open source community.
 BSD license, check license.txt for more information
 All text above, and the splash screen below must be
 included in any redistribution.
 **************************************************************************/

#include <SPI.h>
#include <Wire.h>
#include <Adafruit_GFX.h>
#include <Adafruit_SSD1306.h>

#define SCREEN_WIDTH 128 // OLED display width, in pixels
#define SCREEN_HEIGHT 32 // OLED display height, in pixels

// Declaration for SSD1306 display connected using software SPI (default case):
#define OLED_MOSI   9
#define OLED_CLK   10
#define OLED_DC    13
#define OLED_CS    12
#define OLED_RESET 11
Adafruit_SSD1306 display(SCREEN_WIDTH, SCREEN_HEIGHT,
  OLED_MOSI, OLED_CLK, OLED_DC, OLED_RESET, OLED_CS);

/* Comment out above, uncomment this block to use hardware SPI
#define OLED_DC     6
#define OLED_CS     7
#define OLED_RESET  8
Adafruit_SSD1306 display(SCREEN_WIDTH, SCREEN_HEIGHT,
  &SPI, OLED_DC, OLED_RESET, OLED_CS);
*/

#define NUMFLAKES     10 // Number of snowflakes in the animation example

#define LOGO_HEIGHT   16
#define LOGO_WIDTH    16
static const unsigned char PROGMEM logo_bmp[] =
{ 0b00000000, 0b11000000,
  0b00000001, 0b11000000,
  0b00000001, 0b11000000,
  0b00000011, 0b11100000,
  0b11110011, 0b11100000,
  0b11111110, 0b11111000,
  0b01111110, 0b11111111,
  0b00110011, 0b10011111,
  0b00011111, 0b11111100,
  0b00001101, 0b01110000,
  0b00011011, 0b10100000,
  0b00111111, 0b11100000,
  0b00111111, 0b11110000,
  0b01111100, 0b11110000,
  0b01110000, 0b01110000,
  0b00000000, 0b00110000 };

void setup() {
  Serial.begin(9600);

  // SSD1306_SWITCHCAPVCC = generate display voltage from 3.3V internally
  if(!display.begin(SSD1306_SWITCHCAPVCC)) {
    Serial.println(F("SSD1306 allocation failed"));
    for(;;); // Don't proceed, loop forever
  }

  // Show initial display buffer contents on the screen --
  // the library initializes this with an Adafruit splash screen.
  display.display();
  delay(2000); // Pause for 2 seconds

  // Clear the buffer
  display.clearDisplay();

  // Draw a single pixel in white
  display.drawPixel(10, 10, SSD1306_WHITE);

  // Show the display buffer on the screen. You MUST call display() after
  // drawing commands to make them visible on screen!
  display.display();
  delay(2000);
  // display.display() is NOT necessary after every single drawing command,
  // unless that's what you want...rather, you can batch up a bunch of
  // drawing operations and then update the screen all at once by calling
  // display.display(). These examples demonstrate both approaches...

  testdrawline();      // Draw many lines

  testdrawrect();      // Draw rectangles (outlines)

  testfillrect();      // Draw rectangles (filled)

  testdrawcircle();    // Draw circles (outlines)

  testfillcircle();    // Draw circles (filled)

  testdrawroundrect(); // Draw rounded rectangles (outlines)

  testfillroundrect(); // Draw rounded rectangles (filled)

  testdrawtriangle();  // Draw triangles (outlines)

  testfilltriangle();  // Draw triangles (filled)

  testdrawchar();      // Draw characters of the default font

  testdrawstyles();    // Draw 'stylized' characters

  testscrolltext();    // Draw scrolling text

  testdrawbitmap();    // Draw a small bitmap image

  // Invert and restore display, pausing in-between
  display.invertDisplay(true);
  delay(1000);
  display.invertDisplay(false);
  delay(1000);

  testanimate(logo_bmp, LOGO_WIDTH, LOGO_HEIGHT); // Animate bitmaps
}

void loop() {
}

void testdrawline() {
  int16_t i;

  display.clearDisplay(); // Clear display buffer

  for(i=0; i<display.width(); i+=4) {
    display.drawLine(0, 0, i, display.height()-1, SSD1306_WHITE);
    display.display(); // Update screen with each newly-drawn line
    delay(1);
  }
  for(i=0; i<display.height(); i+=4) {
    display.drawLine(0, 0, display.width()-1, i, SSD1306_WHITE);
    display.display();
    delay(1);
  }
  delay(250);

  display.clearDisplay();

  for(i=0; i<display.width(); i+=4) {
    display.drawLine(0, display.height()-1, i, 0, SSD1306_WHITE);
    display.display();
    delay(1);
  }
  for(i=display.height()-1; i>=0; i-=4) {
    display.drawLine(0, display.height()-1, display.width()-1, i, SSD1306_WHITE);
    display.display();
    delay(1);
  }
  delay(250);

  display.clearDisplay();

  for(i=display.width()-1; i>=0; i-=4) {
    display.drawLine(display.width()-1, display.height()-1, i, 0, SSD1306_WHITE);
    display.display();
    delay(1);
  }
  for(i=display.height()-1; i>=0; i-=4) {
    display.drawLine(display.width()-1, display.height()-1, 0, i, SSD1306_WHITE);
    display.display();
    delay(1);
  }
  delay(250);

  display.clearDisplay();

  for(i=0; i<display.height(); i+=4) {
    display.drawLine(display.width()-1, 0, 0, i, SSD1306_WHITE);
    display.display();
    delay(1);
  }
  for(i=0; i<display.width(); i+=4) {
    display.drawLine(display.width()-1, 0, i, display.height()-1, SSD1306_WHITE);
    display.display();
    delay(1);
  }

  delay(2000); // Pause for 2 seconds
}

void testdrawrect(void) {
  display.clearDisplay();

  for(int16_t i=0; i<display.height()/2; i+=2) {
    display.drawRect(i, i, display.width()-2*i, display.height()-2*i, SSD1306_WHITE);
    display.display(); // Update screen with each newly-drawn rectangle
    delay(1);
  }

  delay(2000);
}

void testfillrect(void) {
  display.clearDisplay();

  for(int16_t i=0; i<display.height()/2; i+=3) {
    // The INVERSE color is used so rectangles alternate white/black
    display.fillRect(i, i, display.width()-i*2, display.height()-i*2, SSD1306_INVERSE);
    display.display(); // Update screen with each newly-drawn rectangle
    delay(1);
  }

  delay(2000);
}

void testdrawcircle(void) {
  display.clearDisplay();

  for(int16_t i=0; i<max(display.width(),display.height())/2; i+=2) {
    display.drawCircle(display.width()/2, display.height()/2, i, SSD1306_WHITE);
    display.display();
    delay(1);
  }

  delay(2000);
}

void testfillcircle(void) {
  display.clearDisplay();

  for(int16_t i=max(display.width(),display.height())/2; i>0; i-=3) {
    // The INVERSE color is used so circles alternate white/black
    display.fillCircle(display.width() / 2, display.height() / 2, i, SSD1306_INVERSE);
    display.display(); // Update screen with each newly-drawn circle
    delay(1);
  }

  delay(2000);
}
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

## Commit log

2024-09-24 Adds KiCAD Project file to KiCAD folder
    [coffee-scale.kicad_pcb, coffee-scale.kicad_sch]
2024-09-24 Update Schematic
    [coffee-scale.kicad_sch]
2024-09-24 Added load cell symbol and made connection to the HX711
    [coffee-scale.kicad_sch]
2024-09-24 Update on KiCad
    [coffee-scale.kicad_sch]
2024-10-01 Update Schematic
    Creates individual sheets for different major moving part sections
    [ESP32-S3.kicad_sch, coffee-scale.kicad_sch, eInkDisplay.kicad_sch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]
2024-11-09 Miscellaneous edits
    [coffee-scale.kicad_sch]
2024-11-10 Update Stage 1 & Stage 2
    [coffee-scale.kicad_sch]
2024-11-13 Update schematic to include USB-C connector
    [coffee-scale.kicad_sch]
2024-11-13 Create logbook 11-12-24.md and update schematic
    [coffee-scale.kicad_sch]
2024-11-14 Code with complete funtionality
    - Sounds when buttons are pressed
    - Tare
    - Timer
    - Deep sleep
    - Flow rate
2024-11-14 Deep sleep sample code from webite
2024-11-14 Test for the timer functionality
2024-12-10 Add files via upload
    Update version with PCB design complete with traces
    [coffee-scale.kicad_pcb, coffee-scale.kicad_sch]
2024-12-11 PCB Update
    [coffee-scale.kicad_pcb, coffee-scale.kicad_sch]
2024-12-12 Update footprints
    [coffee-scale.csv, coffee-scale.kicad_sch]
2024-12-16 logbook and PCB routing edits
    [coffee-scale.kicad_pcb]
2024-12-19 Update Coffee_Scale_Complete_Functionality.ino
    Stabilize flow rate and weight display
    [Coffee_Scale_Complete_Functionality.ino]
